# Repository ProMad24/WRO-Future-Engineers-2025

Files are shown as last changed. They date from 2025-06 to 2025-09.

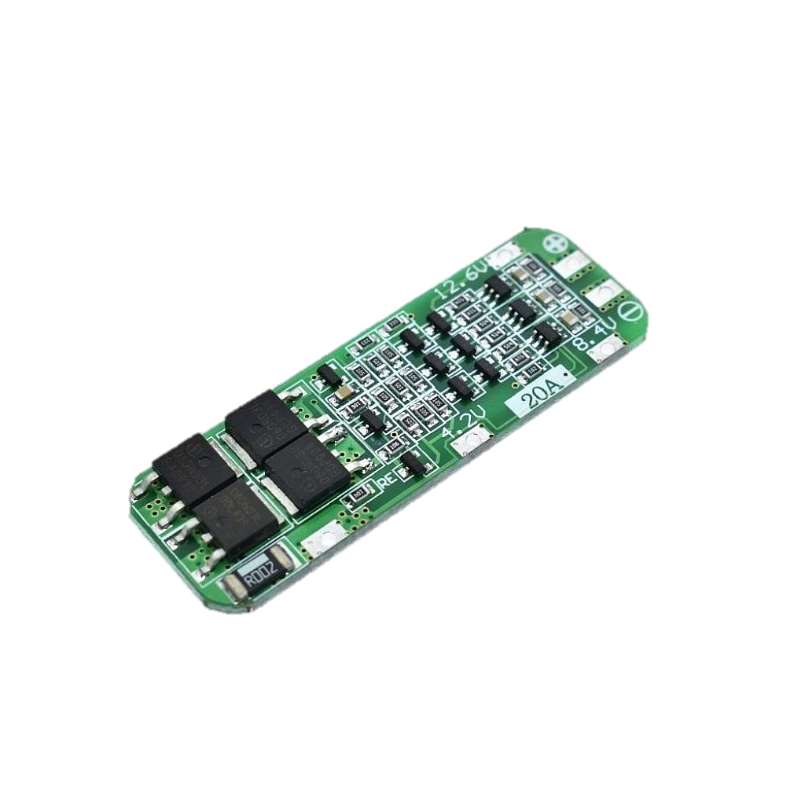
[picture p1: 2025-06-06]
Schemes and Electromechanical Components/20A Protection Circuit For The Batteries.png

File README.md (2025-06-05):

# WRO-Future-Engineers-2025
The Official WRO Future Engineers 2025 Repository of The Syrian Team ProMad

# Introdution :
In pursuit of comfort, humans have always sought easier ways of travel, one example being the self-driving car. An “autonomous” car is a vehicle capable of sensing its environment and operating without human involvement. Driven by curiosity, humanity has reached the necessary technological advancements to achieve a truly autonomous car. Thus, in our project we strive to design, then build a car that is able to move independently while making optimal decisions. Moreover, we extend this work to incorporate obstacle avoidance. In order to achieve our objectives, we developed an integrated system using a Raspberry Pi Model B, which receives and processes information to make decisions before transmitting signals to execute specific commands.

Our approach to the competition was structured into two parts, each addressing a specific challenge. However, both solutions relied on a shared core mechanism: a color-based navigation system.

To inform readers about the vehicle's design, we outline its electromechanical components in the following list:
1)	Raspberry Pi 4 Model B: This single-board computer (SBC) acts as the central processing unit of the vehicle, handling image analysis and motor control to ensure precise navigation.
2)	PiCamera Module 3: A camera designed for the Raspberry Pi, enabling image alongside video capture before transmitting data to the board for processing.
3)	G12-N20 Geared Mini DC Motor: A compact yet powerful motor that enables forward and reverse rotation of the vehicle’s rear wheels.
4)	SG90 Servo Motor: With its precise angular rotation, this servo motor is essential for steering the vehicle’s front wheels, ensuring accurate directional control.
5)	Addressable RGB LED: This LED acts as a real-time debugger for the vehicle, changing colors based on its signals and commands to provide immediate visual feedback.

For the codes with their explanation, detailed information about the electromechanical components alongside many more, feel free to explore the various folders in the repository of the team 😊.

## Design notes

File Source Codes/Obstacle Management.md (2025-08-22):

# Obstacle Challenge:
The solution implemented for this challenge integrates a color-based navigation system to complete the laps around the mat and execute the parking process. The robot utilizes its Pi Camera to detect red and green pillars, which serve as steering indicators. Upon identifying a red pillar, the system transmits signals to the Raspberry Pi, prompting a rightward steering adjustment. Conversely, detecting a green pillar triggers a leftward turn, ensuring precise directional control. The parking lot is consistently positioned within the starting section, allowing the robot to initiate its final maneuver upon completing three laps. At this stage, the system scans for magenta pixels, identifying the parking lot’s location. Following this step, the robot navigates toward the designated area, executing a controlled parking sequence. This integrated approach enhances autonomous navigation, obstacle recognition, and precise parking alignment, optimizing the robot’s overall performance.

Let’s dive into this mechanism deeper with the following steps:

**1. Starting The Robot:**
In the obstacle challenge, the robot's mechanism is activated by first turning on the main power switch, which initiates the circuit. The program is then manually started by pressing a push button. Following this boot-up sequence, the robot's image processing begins, using the same methodology as in the open challenge. This involves capturing and analyzing visual data to guide the robot's subsequent actions.

**2. Object and Wall Detection:**
Once the image is in the HSV format, the process_hsv() function analyzes the pixels to identify key elements:
•	Walls: Pixels with a low value (brightness less than 70) are identified as walls. The code calculates the density of these pixels on both the left and right sides of the frame, providing an estimate of the robot's proximity to a wall. This is a crucial input for the steering algorithm.
•	Traffic Lights: The script identifies red and green traffic lights based on their hue and saturation values. For instance, red traffic lights are identified by a hue value less than 15 or greater than 175, while green traffic lights are identified by a hue value between 45 and 90. These pixels are used to create separate masks for each color.
•	Parking Gate: A purple parking gate is detected using a similar method, identifying pixels within a specific hue, saturation, and value range to create a mask.

**3. Contour Analysis:** 
After the masks are generated, the script uses cv2.findContours() to identify contiguous shapes of each color. The process_traffic_contours() and process_parking_contours() functions then iterate through these shapes (contours) to find the largest one, which is assumed to be the target object. The x and y coordinates of the centroid of the largest contour are stored, along with its area and type (red or green).steps.

**4. Steering and Motor Control**
This is where the robot acts on the visual data. The steering direction is calculated using a proportional control (P-controller) algorithm. The Err variable, or error, is calculated based on the horizontal position of the detected traffic light. A positive error value indicates the traffic light is to the left of the center, and a negative value indicates it is to the right. The steering direction, dir, is then calculated as Err * kp, where kp is a constant gain of 0.30. This makes the steering proportional to the error, causing the robot to turn more sharply the farther it is from the center. The servo() function then takes this dir value and converts it into a PWM (Pulse Width Modulation) signal to control the servo motor, which adjusts the robot's wheels. The script also includes a fail-safe mechanism where if the wall density is too high, the robot will turn sharply away to prevent a collision.

**5. Mission Logic and Overrides:**
The code contains a complex state machine with various conditions that override the standard steering algorithm:
•	Quadrant Counting: The robot tracks its progress by counting blue and orange lines, which define different quadrants of the course.
•	Parking Sequence: In later quadrants, the script overrides the traffic light detection and initiates a new steering routine to align with and approach the parking gate. This routine uses the wall detection logic to align the robot parallel to the walls before stopping when the purple parking gate is close enough. The STOP variable is set to True to halt the robot and end the program once the mission is complete.

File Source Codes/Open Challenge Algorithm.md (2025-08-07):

# 1. Open Challenge: 

To address the challenge, we developed a camera-based algorithm utilizing the Raspberry Pi 4 Model B alongside the Pi Camera Model 3. This system enables precise linear alignment, ensuring the robot maintains a consistent trajectory along the mat’s walls throughout the four straightforward sections. The steering mechanism is dynamically adjusted based on color recognition, allowing the robot to detect and respond to walls when encountering a corner. Additionally, the system incorporates a lap-counting function relying on the strips in corners, enabling the robot to track its completed laps before executing a stop command. This integrated approach enhances autonomous navigation, spatial awareness, and real-time decision-making, optimizing the robot’s overall performance.

To further elaborate on this mechanism, the following is a step-by-step breakdown of its functionality:

### *__1.1.__ Starting The Robot:*
- Once the robot is placed on the mat, we close the robot’s circuit using a simple switch to provide it with power. Then, it initiates the program execution with a button press, activating its driving mechanism.
------
### *__1.2.__	Image Processing:*
- The Pi Camera captures an image of the robot’s field of view, transmitting it to the Raspberry Pi for processing.

- Much like the human eye, the camera is positioned to capture a flipped image at a resolution of 640×480 pixels. Upon receiving the photograph from the PiCamera 3, the Rpi4 immediately initiates the processing sequence. This sequence involves flipping the image, adjusting its resolution, and performing color detection.

- With more details, the Rpi reduces the resolution to 320×120 pixels and removes the top 40 rows to isolate the area containing the mat. Keeping in mind that it structures the pixel data into arrays using Python, while leveraging the NumPy library for efficient manipulation. This technique not only facilitates resolution reduction but also contributes to image inversion, as the pixels are reordered in reverse to produce the correct visual phase.

- We arrive at the final stage of the image processing sequence: color detection. The Rpi is responsible for identifying a variety of colors by relying on the HSV (Hue, Saturation, Value) color model, which ensures optimal detection accuracy. Specifically, the algorithm recognizes walls as black pixels, while blue and orange pixels indicate corner strips.
  
  - Moreover, color detection is contingent upon a threshold condition being met. If the pixel count does not surpass this threshold, the robot disregards the orange and blue corner strips. However, if a strip is successfully detected, its state is set to 1, indicating active detection. Once the strip moves out of view, the state transitions to 2, initiating a cooldown phase before the next strip can be registered.
  - Additionally, the algorithm designed for linear alignment relies on detecting the proportional presence of both the left and right walls. To facilitate this, the Rpi splits the image into two halves—one representing the left wall’s black pixels, and the other capturing the right wall’s black pixels—allowing the system to evaluate wall alignment more accurately based on distribution and positioning.
---
### *__1.3.__	Analysis of Given Information and Solving the Challenge:*
- As the Rpi4 interprets the robot’s field of view, it issues optimal commands to execute the designated task. The following outlines these commands step by step:

- <ins>*__Step One:__*</ins> Upon activation—triggered by pressing the start button—the DC motor immediately begins rotating at a speed of 90 RPM. Simultaneously, the PiCamera initiates image analysis.

- <ins>*__Step Two:__*</ins> The PiCamera processes 30 frames per second. For each frame, the Rpi4 evaluates the distribution of black pixels across both halves of the image. It then performs proportional calculations to assess the robot’s alignment relative to the surrounding walls and its distance from the outer boundary. If the robot is properly aligned, the Rpi4 maintains the steering wheels in a forward position without altering the angle. However, if any misalignment is detected, it adjusts the steering angle via the Servo motor using a proportional (P) controller to restore proper orientation.

- <ins>*__Step Three:__*</ins> When the robot encounters a corner, an additional condition is applied to the previous process. Specifically, if the Rpi4 detects an insufficient number of black pixels on either half of the frame, it infers the absence of a wall and authorizes an increase in the steering angle. The direction of the Servo motor’s movement—whether it turns left or right—is determined by the color of the first strip identified: orange strips signal a clockwise turn (positive angle change), while blue strips indicate a counter-clockwise turn (negative angle change).
  - Furthermore, these colored strips serve as corner counters. Each time the robot detects a strip, it increments its corner count by one. Once the count reaches twelve, the robot terminates its operation. Plus, to prevent the simultaneous detection of both strips, a brief delay is introduced following the observation of one.

- <ins>*__Added Feature:__*</ins> An Assembly LED was installed to provide visual feedback on the robot’s readings. It reflects key states such as the detection of different colors. Further details are addressed in a separate directory.

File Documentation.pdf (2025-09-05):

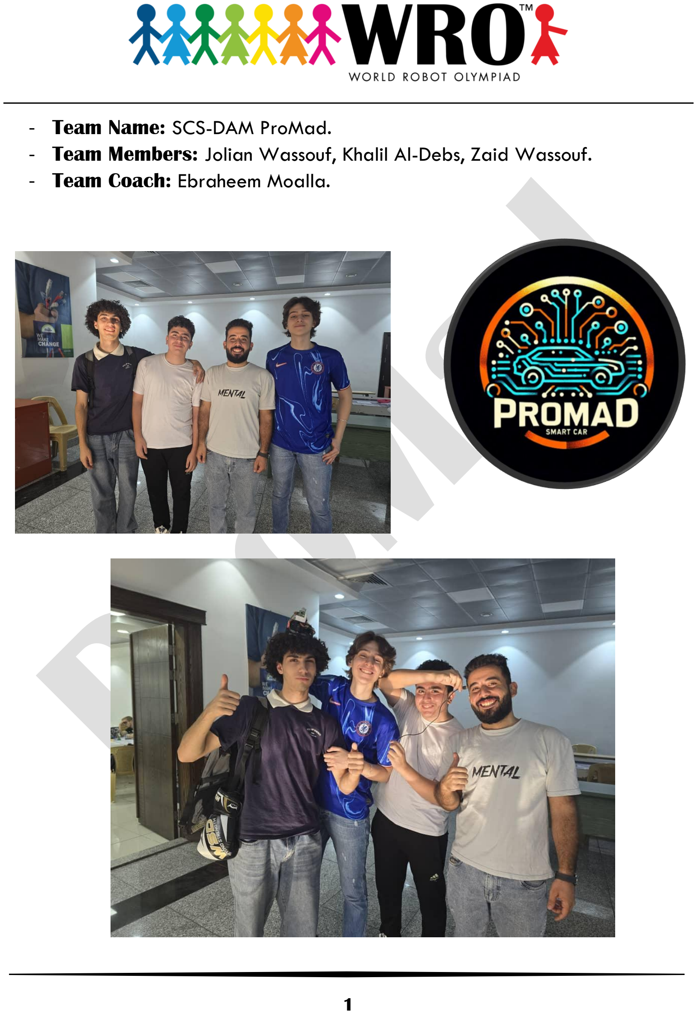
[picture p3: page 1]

1

- Team Name: SCS-DAM ProMad.
- Team Members: Jolian Wassouf, Khalil Al-Debs, Zaid Wassouf.
- Team Coach: Ebraheem Moalla.

2

## Table of Contents:

. Team Members | P.1

### 1. Introduction | P.3

### 2. Solution | P.3-12

1. Open Challenge | P.3-7
2. Obstacle Challenge | P.8-12

### 3. Mobility Management | P.13-23

1. The Steering Assembly | P.13-17
2. The Driving Assembly | P.18-21
3. The Robot’s Body / 3D Design | P.22-23
4. The Mobility Measurement | P.23

### 4. Power and Sense Management | P.24-37

1. The Robot’s Power Source | P.24-27
2. Main Components | P.28-30
3. Wiring Diagrams | P.31-32
4. Sensing | P.33-37

### 5. The Robot’s Evolution | P.38-45

1. Past | P.38-41
2. Present | P.42
3. Future | P.43-45

### 6. The Vehicle’s Photos | P.46-51

### 7. Links and Credits | P.52

3

### 1. Introduction:

In pursuit of comfort, humans have always sought easier ways of travel, one example being the self-driving car. An “autonomous” car is a vehicle capable of sensing its environment and operating without human involvement. Driven by curiosity, humanity has reached the necessary technological advancements to achieve a truly autonomous car. Thus, in our project we strive to design, then build a car that is able to move independently while making optimal decisions. Moreover, we extend this work to incorporate obstacle avoidance. In order to achieve our objectives, we developed an integrated system using a Raspberry Pi 4 Model B, which receives and processes information to make decisions before transmitting signals to execute specific commands.

### 2. Solution:

We followed a solution of two parts, one for each task.

### 1. Open Challenge:

To address the challenge, we developed a camera-based algorithm utilizing the Raspberry Pi 4 Model B alongside the Pi Camera Model 3. This system enables precise linear alignment, ensuring the robot maintains a consistent trajectory along the mat’s walls throughout the four straightforward sections. The steering mechanism is dynamically adjusted based on color recognition, allowing the robot to detect and respond to walls when encountering a corner. Additionally, the system incorporates a lap-counting function relying on the strips in corners, enabling the robot to track its completed laps before executing a stop command. This integrated approach enhances autonomous navigation, spatial awareness, and real-time decision-making, optimizing the robot’s overall performance. Lines of code in addition to performance videos are provided in the Links section.

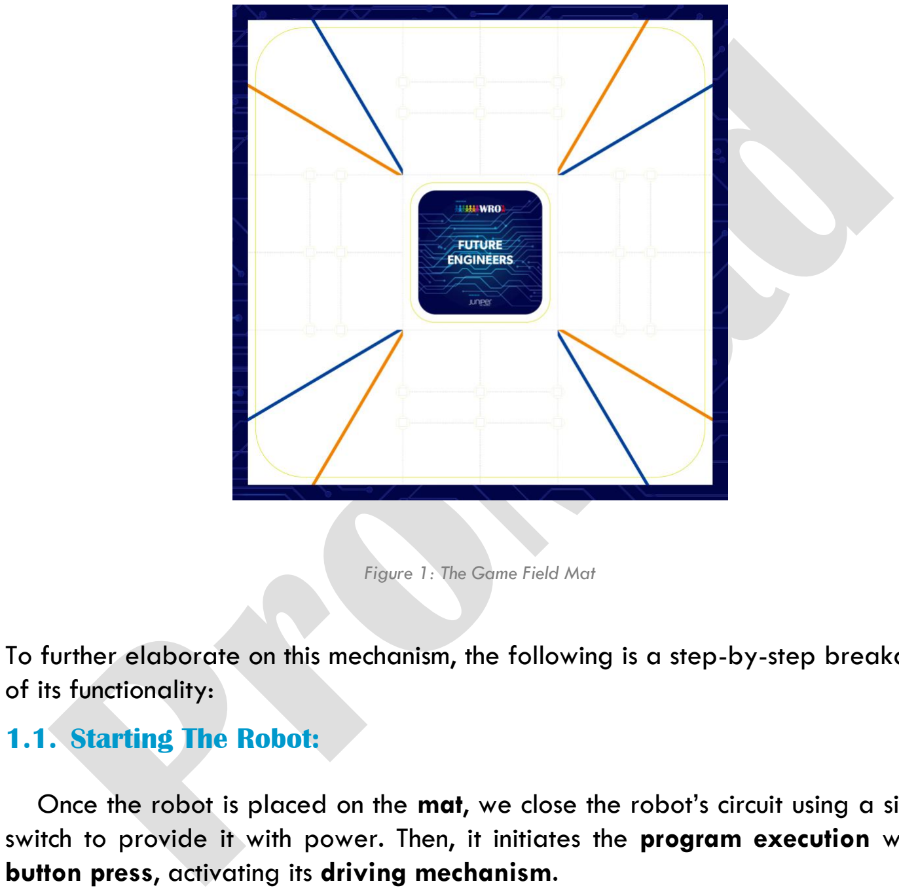
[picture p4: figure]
of its functionality:; 1.1. Starting The Robot:; Figure 1: The Game Field Mat

4

To further elaborate on this mechanism, the following is a step-by-step breakdown

Once the robot is placed on the mat, we close the robot’s circuit using a simple switch to provide it with power. Then, it initiates the program execution with a button press, activating its driving mechanism.

### 1.2. Image Processing:

The Pi Camera captures an image of the robot’s field of view, transmitting it to the Raspberry Pi 4 Model B for processing.

5

Much like the human eye, the camera is positioned to capture a flipped image at a resolution of 640×480 pixels. Upon receiving the photograph from the PiCamera 3, the Raspberry Pi 4 immediately initiates the processing sequence. This sequence involves flipping the image, adjusting its resolution, and performing color detection.

With more details, the Rpi4 reduces the resolution to 320×120 pixels and removes the top 40 rows to isolate the area containing the mat. Keeping in mind that it structures the pixel data into arrays using Python, while leveraging the NumPy library for efficient manipulation. This technique not only facilitates resolution reduction but also contributes to image inversion, as the pixels are reordered in reverse to produce the correct visual phase.

Figure 3: Raw Image | Figure 2: Processed Image

6

We arrive at the final stage of the image processing sequence: color detection. The Raspberry Pi 4 is responsible for identifying a variety of colors by relying on the HSV (Hue, Saturation, Value) color model, which ensures optimal detection accuracy. Specifically, the algorithm recognizes walls as black pixels, while blue and orange pixels indicate corner strips.

Moreover, color detection is contingent upon a threshold condition being met. If the pixel count does not surpass this threshold, the robot disregards the orange and blue corner strips. However, if a strip is successfully detected, its state is set to 1, indicating active detection. Once the strip moves out of view, the state transitions to 2, initiating a cooldown phase before the next strip can be registered.

Additionally, the algorithm designed for linear alignment relies on detecting the proportional presence of either the left or right walls. To facilitate this, the Rpi4 splits the image into two halves—one representing the left wall’s black pixels, and the other capturing the right wall’s black pixels—allowing the system to evaluate wall alignment more accurately based on distribution and positioning.

Figure 5: Walls Detection –
walls are the white figures | Figure 4: The Robot's View of The Lines

Figure 6: The Identification of Strip Colors

*Blue | *Orange

7

### 1.3. Analysis of Given Information and Solving the Challenge:

As the Rpi4 interprets the robot’s field of view, it issues optimal commands to execute the designated task. The following outlines these commands step by step:

Step One: Upon activation—triggered by pressing the start button—the DC motor immediately begins rotating at a speed of 200 RPM. Simultaneously, the PiCamera initiates image analysis.

Step Two: The PiCamera processes 30 frames per second. For each frame, the Rpi4 evaluates the distribution of black pixels across both halves of the image. It then performs proportional calculations to assess the robot’s alignment relative to the surrounding walls and its distance from the outer boundary. If the robot is properly aligned, the Rpi4 maintains the steering wheels in a forward position without altering the angle. However, if any misalignment is detected, it adjusts the steering angle via the Servo motor using a proportional (P) controller to restore proper orientation.

Step Three: When the robot encounters a corner, the wall that the robot relies on for the proportions—whether it is the left or right wall—is determined by the color of the first strip identified: orange strips signal a clockwise turn (left wall proportion), while blue strips indicate a counter-clockwise turn (right wall proportion).

Furthermore, these colored strips serve as corner counters. Each time the robot detects a strip, it increments its quadrant count by one. Once the count reaches twelve, the robot terminates its operation. Plus, to prevent the simultaneous detection of both strips, a brief delay is introduced following the observation of one.

Added Feature: An Assembly LED was installed to provide visual feedback on the robot’s readings. It reflects key states such as the detection of different colors. Further details are addressed in a separate directory.

8

Figure 7: Obstacle Challenge Map

### 2. Obstacle Challenge:

The solution implemented for this challenge integrates a color-based navigation system to complete the laps around the mat and execute the parking process. The robot utilizes its Pi Camera to detect red and green pillars, which serve as steering indicators. Upon identifying a red pillar, the system transmits signals to the Raspberry Pi, prompting a rightward steering adjustment. Conversely, detecting a green pillar triggers a leftward turn, ensuring precise directional control. The parking lot is consistently positioned within the starting section, allowing the robot to initiate its final maneuver upon completing three laps. At this stage, the system scans for magenta pixels, identifying the parking lot’s location. Following this step, the robot navigates toward the designated area, executing a controlled parking sequence. This integrated approach enhances autonomous navigation, obstacle recognition, and precise parking alignment, optimizing the robot’s overall performance. Lines of code besides performance videos are provided as a QR code in the Links section.

9

Let’s dive into this mechanism deeper with the following steps:

### 2.1. Starting The Robot:

In the obstacle challenge, the robot's mechanism is activated by first turning on the main power switch, which initiates the circuit. The program is then manually started by pressing a push button. Following this boot-up sequence, the robot's image processing begins, using the same methodology as in the open challenge. This involves capturing and analyzing visual data to guide the robot's subsequent actions.

### 2.2. Object and Wall Detection:

Once the image is in the HSV format, the process_hsv() function analyzes the pixels to identify key elements:

- Walls: Pixels with a low value (brightness less than 70) are identified as walls. The code calculates the density of these pixels on both the left and right sides of the frame, providing an estimate of the robot's proximity to a wall. This is a crucial input for the steering algorithm.
- Traffic Lights: The script identifies red and green traffic lights based on their hue and saturation values. For instance, red traffic lights are identified by a hue value less than 15 or greater than 175, while green traffic lights are identified by a hue value between 45 and 90. These pixels are used to create separate masks for each color.
- Parking Gate: A purple parking gate is detected using a similar method, identifying pixels within a specific hue, saturation, and value range to create a mask.

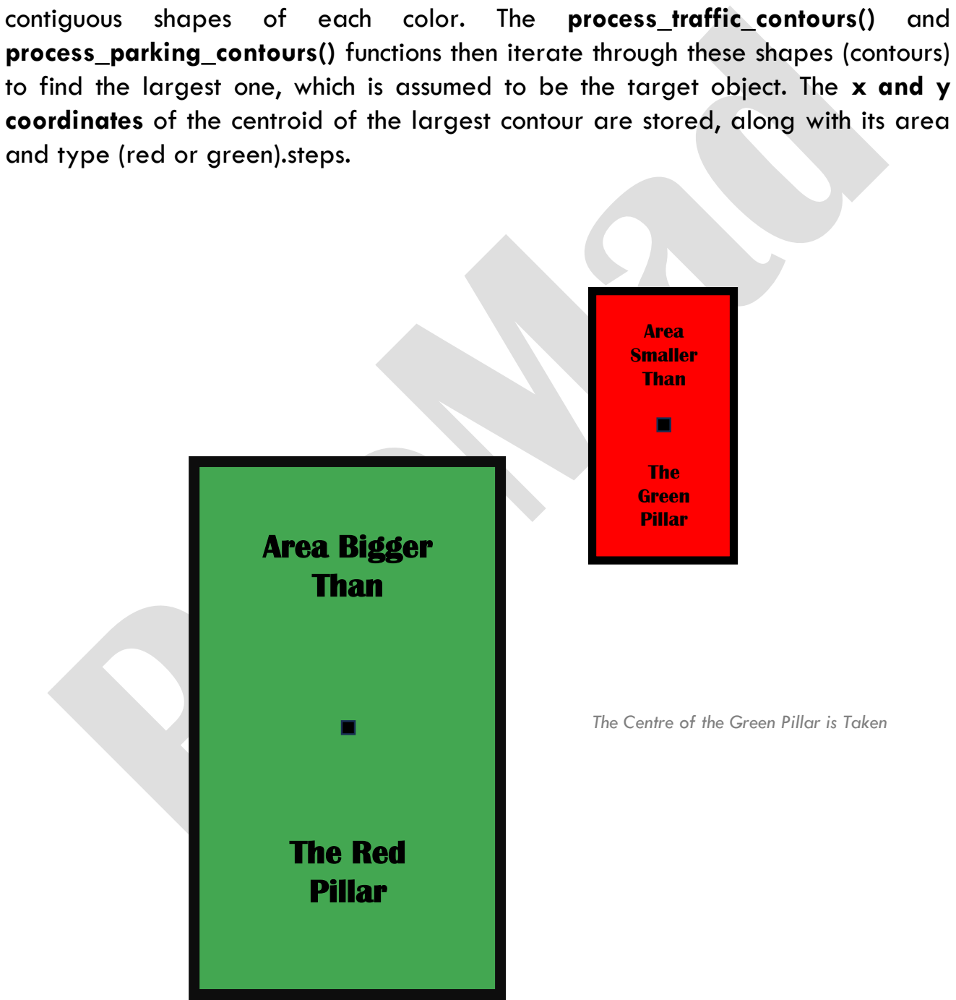
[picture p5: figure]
contiguous; shapes; each; color.; The; process_traffic_contours(); and; and type (red or green).steps.; Area Bigger Than; The Red Pillar; The Centre of the Green Pillar is Taken; Area Smaller Than; The Green Pillar

10

### 2.3. Contour Analysis:

After the masks are generated, the script uses cv2.findContours() to identify

process_parking_contours() functions then iterate through these shapes (contours) to find the largest one, which is assumed to be the target object. The x and y coordinates of the centroid of the largest contour are stored, along with its area

11

### 2.4. Steering and Motor Control

This is where the robot acts on the visual data. The steering direction is calculated using a proportional control (P-controller) algorithm. The Err variable, or error, is calculated based on the horizontal position of the detected traffic light. A positive error value indicates the traffic light is to the left of the center, and a negative value indicates it is to the right. The steering direction, dir, is then calculated as Err * kp, where kp is a constant gain of 0.30. This makes the steering proportional to the error, causing the robot to turn more sharply the farther it is from the center. The servo() function then takes this dir value and converts it into a PWM (Pulse Width Modulation) signal to control the servo motor, which adjusts the robot's wheels. The script also includes a fail-safe mechanism where if the wall density is too high, the robot will turn sharply away to prevent a collision.

Figure 8: Obstacle Management

12

### 2.5. Mission Logic and Overrides:

The code contains a complex state machine with various conditions that override the standard steering algorithm:

- Quadrant Counting: The robot tracks its progress by counting blue and orange lines, which define different quadrants of the course.
- Parking Sequence: In later quadrants, the script overrides the traffic light detection and initiates a new steering routine to align with and approach the parking gate. This routine uses the wall detection logic to align the robot parallel to the walls before stopping when the purple parking gate is close enough. The STOP variable is set to True to halt the robot and end the program once the mission is complete.

13

### 3. Mobility Management:

To clarify how we managed the robot’s mobility, we’re willing to discuss several aspects:

### 1. The Steering Assembly:

To steer the robot properly, we used:

- MG90s Servo Motor:

The MG90s servo motor was specifically selected for this application due to its compact dimensions and its capacity for exceptionally precise angle management. Operating within a voltage range of 4.8V to 6V, it facilitates a full 180° rotation span, which is ideal for angular control tasks. Internally, its accurate motion is regulated by a sophisticated control circuit, which, coupled with a potentiometer for positional feedback, directs a DC motor and gear train. This regulation is achieved via Pulse Width Modulation (PWM) signals, where specific pulse durations within a 20ms cycle correspond to exact angles—a 1.5ms pulse for the center position, with 1ms and 2ms pulses for the opposing extremes.

Furthermore, its performance capabilities are substantiated by a stall torque of approximately 1.8 kg-cm at 4.8V and a rapid response time of 0.10–0.12 seconds per 60° of rotation. The unit's lightweight design, high responsiveness, and seamless integration through a simple three-wire interface (power, ground, and signal) affirm its suitability for tasks demanding precise and dynamic motion control.

Figure 9: MG90s Mini Servo Motor

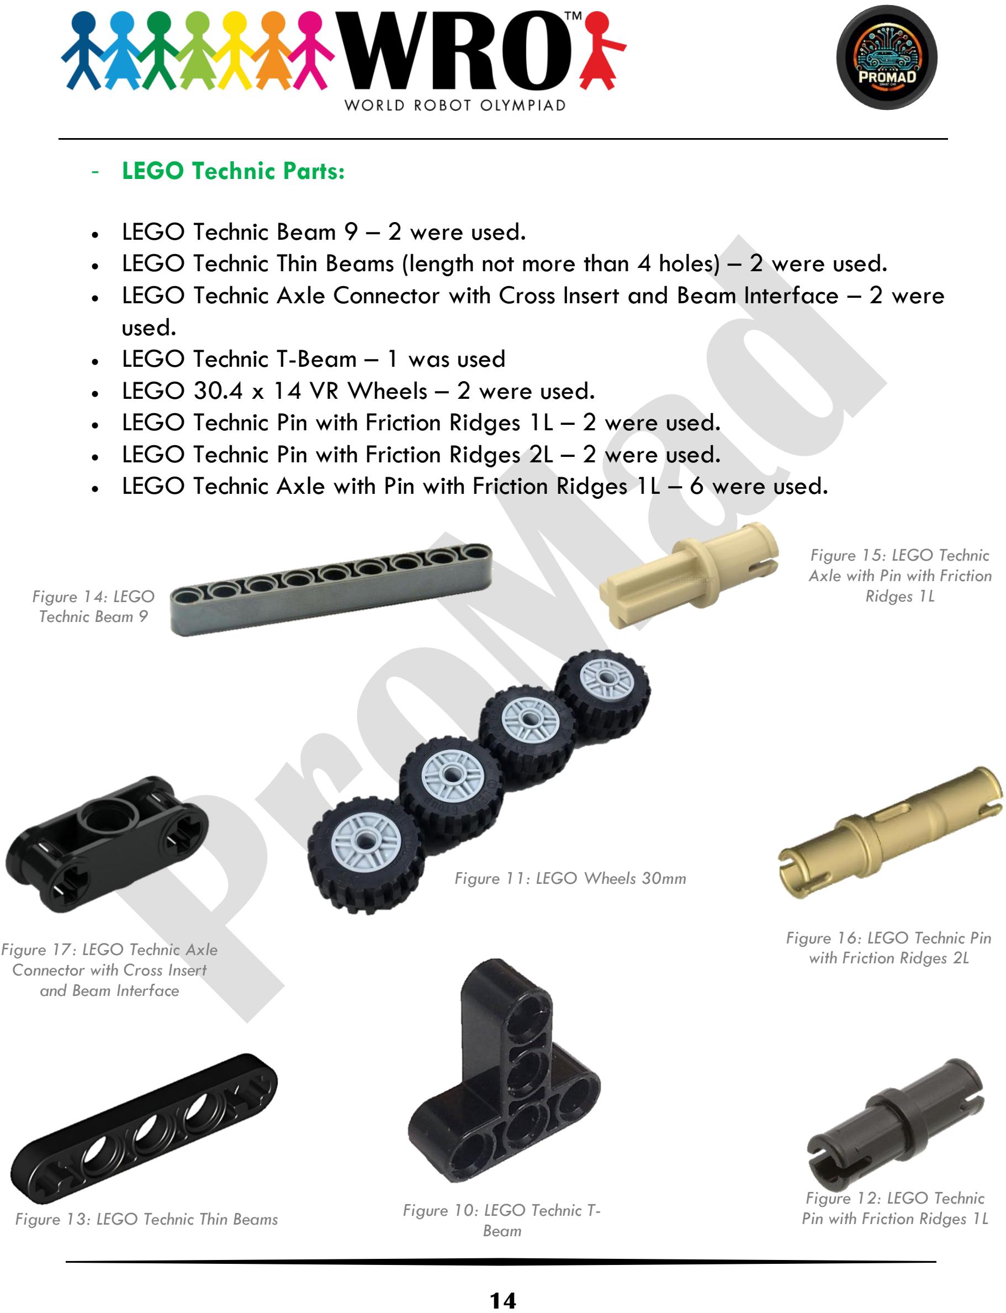
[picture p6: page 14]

14

- LEGO Technic Parts:
- LEGO Technic Beam 9 – 2 were used.
- LEGO Technic Thin Beams (length not more than 4 holes) – 2 were used.
- LEGO Technic Axle Connector with Cross Insert and Beam Interface – 2 were used.
- LEGO Technic T-Beam – 1 was used
- LEGO 30.4 x 14 VR Wheels – 2 were used.
- LEGO Technic Pin with Friction Ridges 1L – 2 were used.
- LEGO Technic Pin with Friction Ridges 2L – 2 were used.
- LEGO Technic Axle with Pin with Friction Ridges 1L – 6 were used.

Figure 15: LEGO Technic
Axle with Pin with Friction
Figure 14: LEGO | Ridges 1L
Technic Beam 9

Figure 17: LEGO Technic Axle Connector with Cross Insert and Beam Interface

Figure 16: LEGO Technic Pin with Friction Ridges 2L

Figure 13: LEGO Technic Thin Beams

Figure 12: LEGO Technic
Pin with Friction Ridges 1L

Figure 11: LEGO Wheels 30mm

Figure 10: LEGO Technic T-Beam

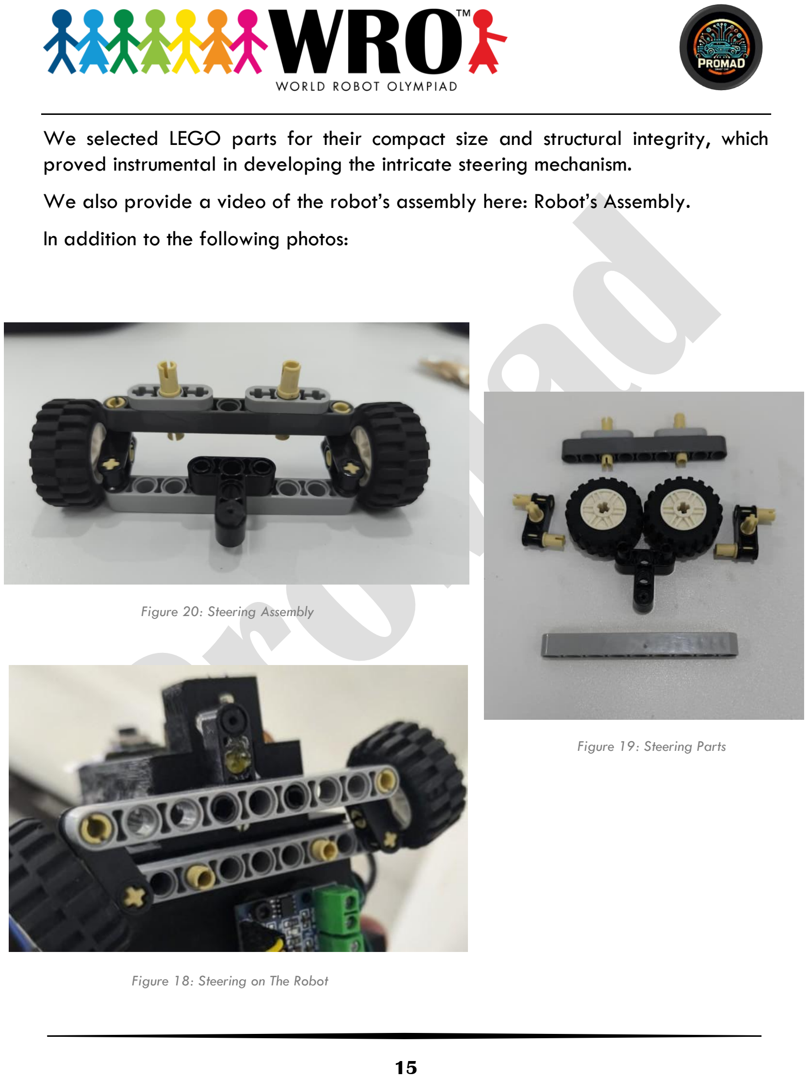
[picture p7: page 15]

15

We selected LEGO parts for their compact size and structural integrity, which proved instrumental in developing the intricate steering mechanism.

We also provide a video of the robot’s assembly here: Robot’s Assembly.

In addition to the following photos:

Figure 20: Steering Assembly

Figure 19: Steering Parts

Figure 18: Steering on The Robot

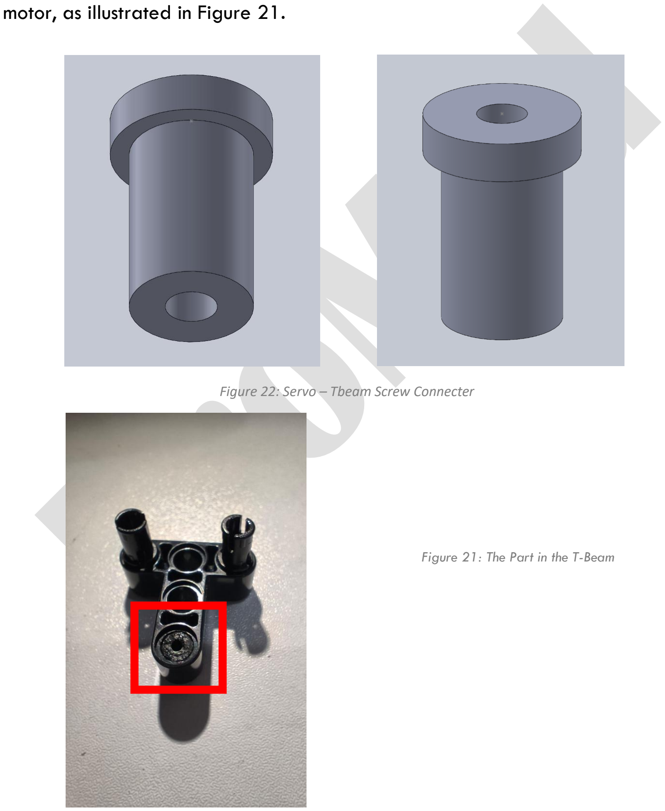
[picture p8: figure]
motor, as illustrated in Figure 21.; Figure 21: The Part in the T-Beam

16

- 3D Part:

This component served as a screw holder, connecting the T-Beam and the servo

Figure 22: Servo – Tbeam Screw Connecter

17

The Steering Algorithm:

The steering logic is implemented in the cycle() function, which is continuously called in the main loop to provide a near real-time response. In the open challenge, the algorithm steers the robot by detecting walls on either side of the path. It calculates an error term based on the number of "wall" pixels detected and then determines the steering direction, dir, by multiplying this error by the proportional gain constant. The calculated dir value is then passed to the servo() function. Similarly, the obstacle challenge also uses wall detection but incorporates more complex logic based on the detection of traffic lights and parking gates. The error term, Err, is derived from the position of the detected traffic light, and the steering is adjusted accordingly. The cycle() function in both codes is executed repeatedly, ensuring the steering is constantly adjusted with each new frame captured by the camera.

18

Figure 23: GA12-N20 Geared Mini DC Motor

### 2. The Driving Assembly:

The driving assembly has a simple idea, let’s navigate it with starting with the components first:

- GA12-N20 Geared Mini DC Motor:

The N20 DC 12V 150RPM gear motor was an ideal choice for this project. We selected this motor specifically for its power efficiency, compact size, and potent drive power, all of which were crucial to our robot's design. The motor's small dimensions were paramount, as they allowed for a streamlined and space-efficient build. Furthermore, the motor's high-torque output, which delivers a rated torque of approximately 2.5 kg-cm and a stall torque reaching nearly 8 kg-cm under heavy loads, provides the robust and responsive movement required for our system. A durable metal gearbox further enhances longevity and reduces wear over time. This motor's compact design, impressive torque efficiency, and robust construction made it a versatile and essential component for our technical application, ensuring reliable performance even in demanding conditions.

19

- L9110 Motor Driver:

The L9110 motor driver is a highly efficient PWM-based control IC designed for high-voltage applications, particularly in automotive and industrial environments. Engineered to regulate LED brightness and motor speed, it operates within a wide voltage range, ensuring adaptability across various systems. The L9110 supports high-current outputs, making it suitable for power-intensive applications. Its integrated protection mechanisms, including overcurrent and thermal shutdown, enhance reliability and longevity. The PWM control ensures precise modulation, optimizing energy efficiency while minimizing heat dissipation. With its compact design and robust electrical specifications, the L9110 stands as a versatile solution for engineers seeking stable and efficient motor control.

In our project, it used with the DC Motor.

Figure 24: L9110 Motor Driver

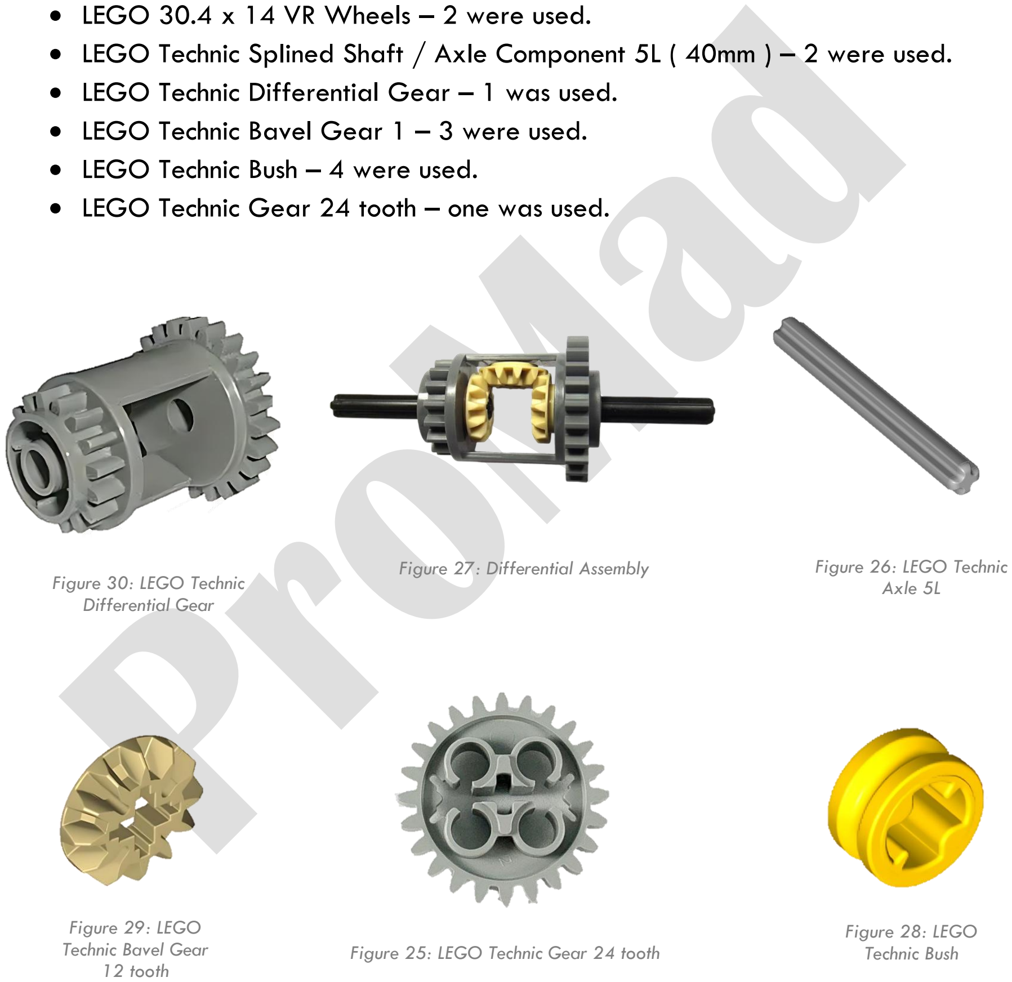
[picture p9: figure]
• LEGO Technic Bush – 4 were used.; Figure 26: LEGO Technic Axle 5L Figure 30: LEGO Technic Differential Gear; Figure 29: LEGO Technic Bavel Gear 12 tooth; Figure 28: LEGO; Figure 27: Differential Assembly

20

- LEGO Parts:
- LEGO 30.4 x 14 VR Wheels – 2 were used.
- LEGO Technic Splined Shaft / Axle Component 5L ( 40mm ) – 2 were used.
- LEGO Technic Differential Gear – 1 was used.
- LEGO Technic Bavel Gear 1 – 3 were used.
- LEGO Technic Gear 24 tooth – one was used.
Figure 25: LEGO Technic Gear 24 tooth | Technic Bush

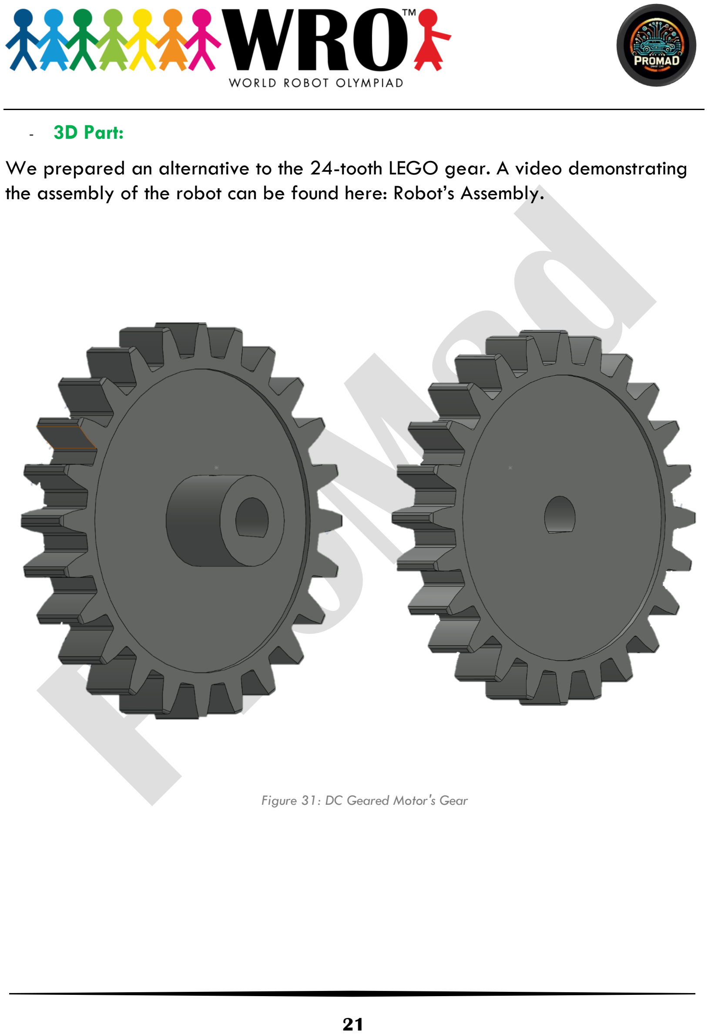
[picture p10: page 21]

21

- 3D Part:

We prepared an alternative to the 24-tooth LEGO gear. A video demonstrating the assembly of the robot can be found here: Robot’s Assembly.

Figure 31: DC Geared Motor's Gear

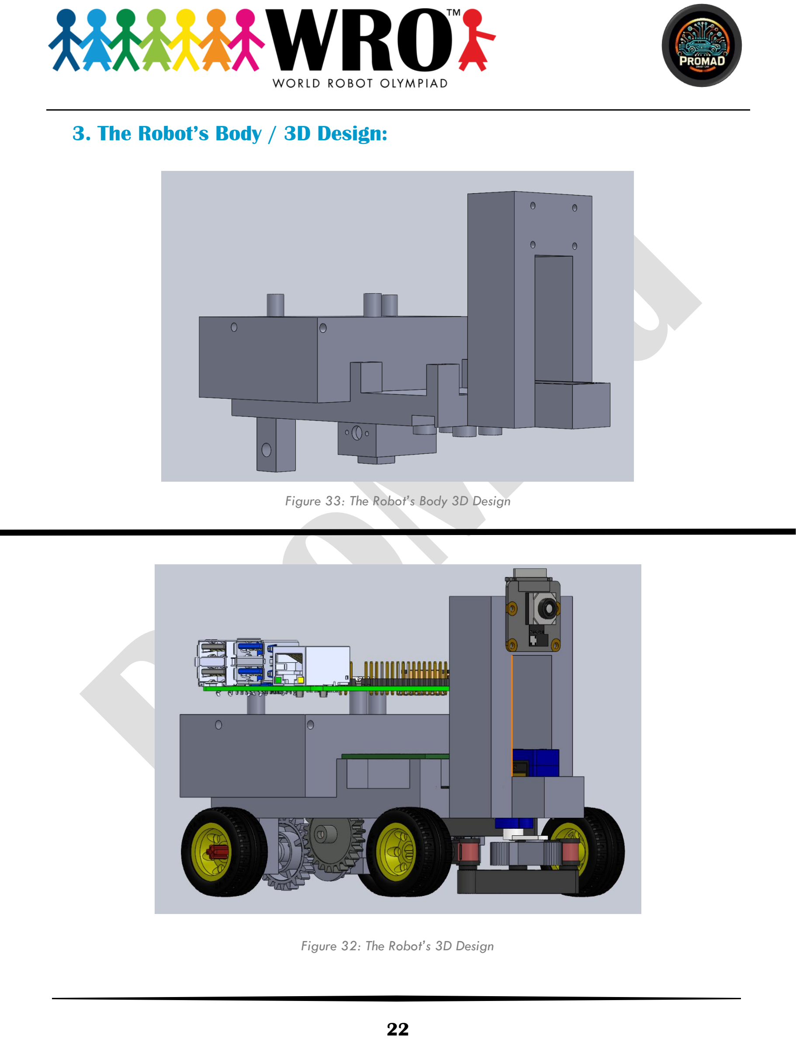
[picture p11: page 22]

22

### 3. The Robot’s Body / 3D Design:

Figure 33: The Robot’s Body 3D Design

Figure 32: The Robot’s 3D Design

23

In selecting the robot's body, our objective was to design a novel and practical model that would effectively address the requirements of the provided challenges. We, therefore, engineered a compact model that could accommodate all necessary components while maintaining a small footprint. For a detailed guide on the robot's assembly, a link to the instructional video can be found in the "Links" section.

### 4. The Mobility Measurement:

In order to accurately calculate the robot's velocity and power output, it is essential to first identify the following parameters:

- The Perimeter of the wheels (Pw):

{we need the radius of the wheels: rw = 30.4mm/2 => rw ≈ 0.015m}

Pw = 2πrw = 2 ⋅ 3.14 ⋅ 0.015 ≈ 0.095m

- The Speed of the motor (wdc): ωⅆc = 150Rpm
- The Voltage and Current supplied to the motor: I = 0.8A || V = 12V

The Velocity of the Robot:
v = Pw ⋅ ωⅆc = 0.095 ⋅ 150 ≈ 14.31 m ⋅ min⁻¹

v ≈ 0.238 m ⋅ s⁻¹

The Power of the Robot

P = V ⋅ I = 12 ⋅ 0.8 = 9.6 Watt

24

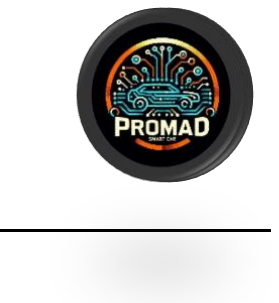
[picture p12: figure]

### 4. Power and Sense Management:

We divide this category into four sections:

### 1. The Robot’s Power Source:

1.1. 3S LiPo Battery Pack with 20A Protection Circuit:

The 3S Lithium Polymer (LiPo) battery pack consists of three cells in series, delivering a nominal voltage of 11.1V and a maximum of 12.6V when fully charged. It features an integrated 20A Battery Management System (BMS) that protects against overcharging, deep discharging, and short circuits, ensuring safe and reliable power delivery.

Thanks to its lightweight pouch construction, the LiPo pack offers flexibility and compactness, which are especially advantageous in robotic applications. Its ability to provide high discharge rates with minimal voltage drop makes it ideal for systems demanding bursts of power. Due to its excellent energy density, thermal stability, and protective features, this pack serves as the primary power source for our robot, enabling efficient, high-performance operation.

Figure 6: 20A Battery Management System (BMS)

Figure 34: LiPo Battery 2500mAh

25

### 1.2. Mini 360 DC-DC Buck Converter // 1.3. DC-DC Buck Converter

Module with USB Type-A Output:

The Mini 360 DC-DC Buck Converter is a compact and efficient voltage regulation module designed to step down higher DC voltages to a lower, adjustable output. Built around the MP2307 chip, it operates within an input range of 4.75V to 23V and delivers an output voltage adjustable between 1V and 17V. Despite its small size—just 17mm by 11mm—it supports a peak current of 3A and a continuous current of 1.8A, making it suitable for applications in robotics, DIY electronics, and embedded systems. In our robot, this module is specifically used to convert the 12V supplied by the batteries into a stable 5V output, which is essential for powering the servo motor and the assembly LED. Its high conversion efficiency, thermal shutdown protection, and onboard potentiometer for voltage tuning make it a reliable choice for compact power management.

In contrast, the DC-DC Buck Converter Module with USB Type-A Output is tailored for powering USB devices directly from a higher voltage source. Typically supporting an input range of 6V to 24V, it steps down the voltage to a fixed 5V output via a standard USB Type-A port, delivering up to 3A of current. This module is ideal for charging smartphones, powering microcontrollers, or supplying regulated 5V to embedded systems. In our robot, it serves the critical function of converting the same 12V battery input into a suitable 5V output for the Raspberry Pi 4 Model B, ensuring stable operation and protecting the board from voltage fluctuations. Its plug-and-play design, built-in protection features, and compatibility with common USB-powered devices make it especially useful in automotive, solar, and portable electronics applications.

Figure 36: Mini 360
DC-DC Buck
Converter

Figure 35: DC-DC Buck
Converter Module with
USB Type-A Output

26

### 1.4. Perfboard // 1.5. Switch:

The Perfboard in our robot serves as the central hub for electrical connectivity, linking all major components into a cohesive and efficient system. It features two input pins designated for the positive and negative poles of the LiPo battery series, which supply the primary 12V power source. Additionally, the board includes a dedicated row of GND pins that are directly connected to the Raspberry Pi 4 Model B, ensuring a stable ground reference across all subsystems. To distribute power effectively, the perfboard provides six output pins for 12V and six output pins for 5V, the latter being regulated through the Mini 360 DC-DC Buck Converter.

Furthermore, the perfboard integrates a USB Type-A converter module, which plays a crucial role in delivering a regulated 5V supply to the Raspberry Pi

### 4 Model B. This setup not only simplifies the wiring architecture but also enhances

the reliability and safety of the robot’s power distribution. By consolidating power inputs, outputs, and grounding into a single board, the perfboard ensures that all components—from servo motors to LEDs—operate smoothly and in coordination, making it an essential element of our robotic system.

And surely, we use a switch to close or open the circuit.

Figure 37: Perfboard | Figure 38: Switch

27

1.6. 470uF 25V Capacitor:

To ensure stable power delivery in our robotic system, especially during motor startup and sudden load transitions, we incorporated a 470 µF / 25 V electrolytic capacitor across the motor driver’s supply rail. This capacitor serves as a local energy reservoir, discharging rapidly when the motor demands a surge of current. By doing so, it prevents voltage dips that could disrupt the operation of critical components such as the Raspberry Pi 4, the PiCamera v3, and the push button interface. We selected this specific capacitance and voltage rating to strike a balance between energy storage capacity and spatial efficiency within the robot’s enclosure. Its presence significantly reduces transient drops and electrical noise, helping us maintain consistent system behavior under dynamic operating conditions

Figure 39: 470uF 25V Capacitor

28

### 2. Main Components:

### 2.1. Pi Camera Module 3:

The Raspberry Pi Camera Module 3 is a state-of-the-art imaging solution designed for seamless integration with Raspberry Pi devices. Equipped with a 12MP Sony IMX708 sensor, it provides autofocus, HDR capability, and enhanced low-light performance, ensuring exceptional image clarity across various applications. Available in standard and wide-angle configurations, as well as NoIR variants for infrared imaging, it offers versatile functionality. With full HD video recording at 30fps, it integrates effortlessly into Raspberry Pi’s open-source camera ecosystem, making it an indispensable tool for photography, live streaming, and AI-driven image processing, thereby pushing creative and technical boundaries.

In our project, the Pi Camera plays a
crucial role in visual data acquisition and object
recognition. It detects black pixels, which represent the walls of the mat, ensuring accurate environmental mapping. Additionally, it identifies orange and blue pixels, marking the four corner lines for precise spatial localization. The camera further recognizes red and green pixels, signifying obstacle pillars, enabling effective navigation and collision avoidance. Moreover, it detects magenta pixels, which represent the walls of the parking lot, allowing for structured positioning within the designated area. Once the visual data is captured, the Pi Camera transmits these signals to the Raspberry Pi, where computational algorithms process the information for real-time analysis and decision-making. This integrated system enhances object detection, spatial awareness, and autonomous control, ensuring optimal performance in dynamic environments.

Figure 7: Raspberry Pi Camera Module 3

29

### 2.2. Raspberry Pi 4 Model B:

The Raspberry Pi 4 Model B is a high-performance single-board computer (SBC) featuring a Broadcom BCM2711 quad-core Cortex-A72 processor clocked at 1.8GHz, our version in this project uses 2GB of LPDDR4-3200 SDRAM. It includes dual micro-HDMI ports for dual 4K display support, Gigabit Ethernet, Bluetooth 5.0, and dual-band Wi-Fi (2.4GHz & 5.0GHz). The board offers two USB 3.0 and two USB 2.0 ports, a 40-pin GPIO header, and MIPI DSI/CSI interfaces for peripherals. The 40-pin GPIO header supports digital I/O, PWM, I2C, SPI, and UART, and it is commonly programmed using Python libraries like RPi.GPIO besides Scratch. The board is powered via USB-C (5V, 3A) and supports Power over Ethernet with an optional PoE HAT.

In our project, this compact yet powerful device, powered by the USB Type-A converter module, serves as the
central processing unit, executing
and managing all computational
commands | essential | for | system
operation. It precisely coordinates the wheel motors, enabling smooth and controlled mobility. Additionally, it
interfaces | with | the | camera,
facilitating image processing and environmental awareness. Beyond these core functions, the device seamlessly integrates with various
components, | ensuring | efficient
communication and execution of all robotic commands. Its high-speed processing capabilities and multi-functional adaptability make it a crucial element in optimizing the
robot's | performance,
responsiveness, and autonomous functionality.

Figure 8: Raspberry Pi 4 Model B

30

### 2.3. WS2812B Assembly LED: **feedback component** // 2.4. Push

Button:

The WS2812B assembly LED is a highly integrated, individually addressable RGB lighting solution that combines a 5050-sized SMD LED with an embedded control IC in a single package. This integration allows each LED to be controlled independently via a single-wire digital interface, significantly simplifying circuit design and reducing the number of required microcontroller pins. Operating within a 3.3V to 5V range, each LED can produce over 16 million colors by modulating the intensity of its red, green, and blue channels through 8-bit PWM control. The data signal propagates from one LED to the next, enabling seamless daisy-chaining of multiple units without complex wiring. This makes the WS2812B ideal for dynamic lighting applications, including status indicators, visual feedback systems, and aesthetic enhancements in embedded and robotic platforms.

In our robot, the WS2812B assembly LED functions as a dynamic visual feedback system, reflecting real-time sensor readings. It is powered via a regulated 5V line from the Mini 360 Buck Converter, with ground referenced to the Raspberry Pi 4 Model B, and controlled through a GPIO pin using libraries like Adafruit NeoPixel. The LED color corresponds to environmental cues detected by the camera: when blue pixels are identified, the robot converts HSV data to RGB and displays blue; similarly, orange, red, green, and magenta are shown when their respective strips or pillars are recognized. This mapping allows quick visual confirmation of object detection and classification. Additionally, a default color is used to indicate the robot’s idle or standby state, ensuring continuous status awareness during operation.

The Push Button is used to start the program.

Figure 40: Push Button | Figure 41: WS2812B Assembly LED

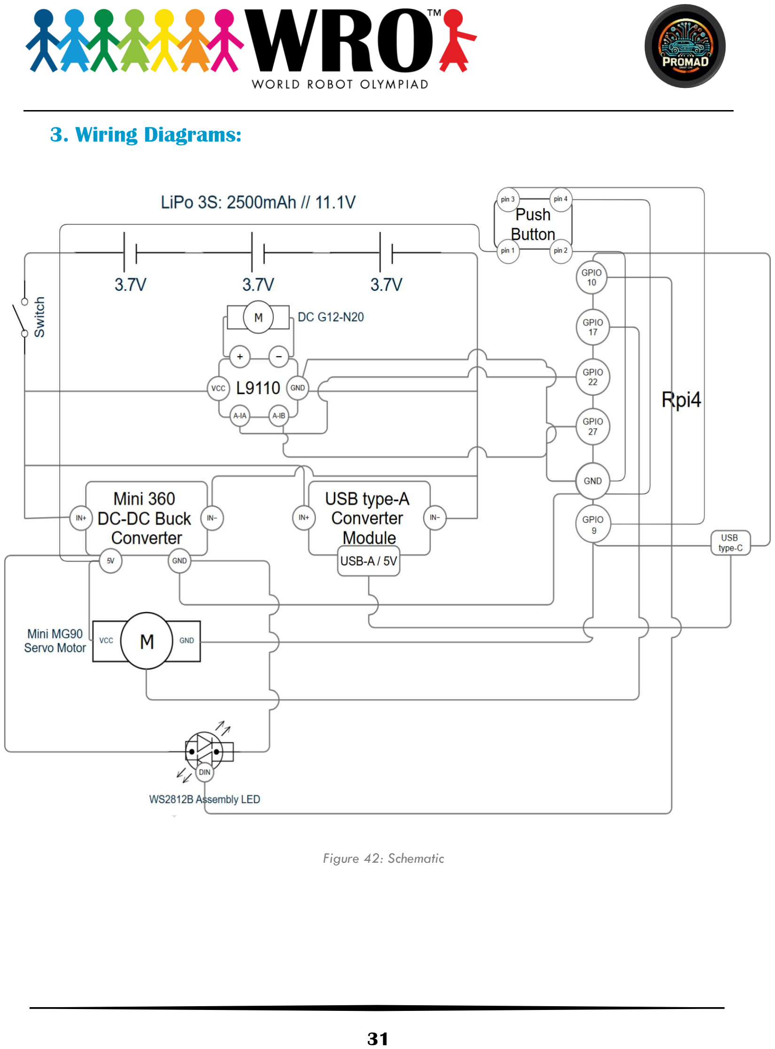
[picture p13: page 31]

31

### 3. Wiring Diagrams:

Figure 42: Schematic

GPIO
9

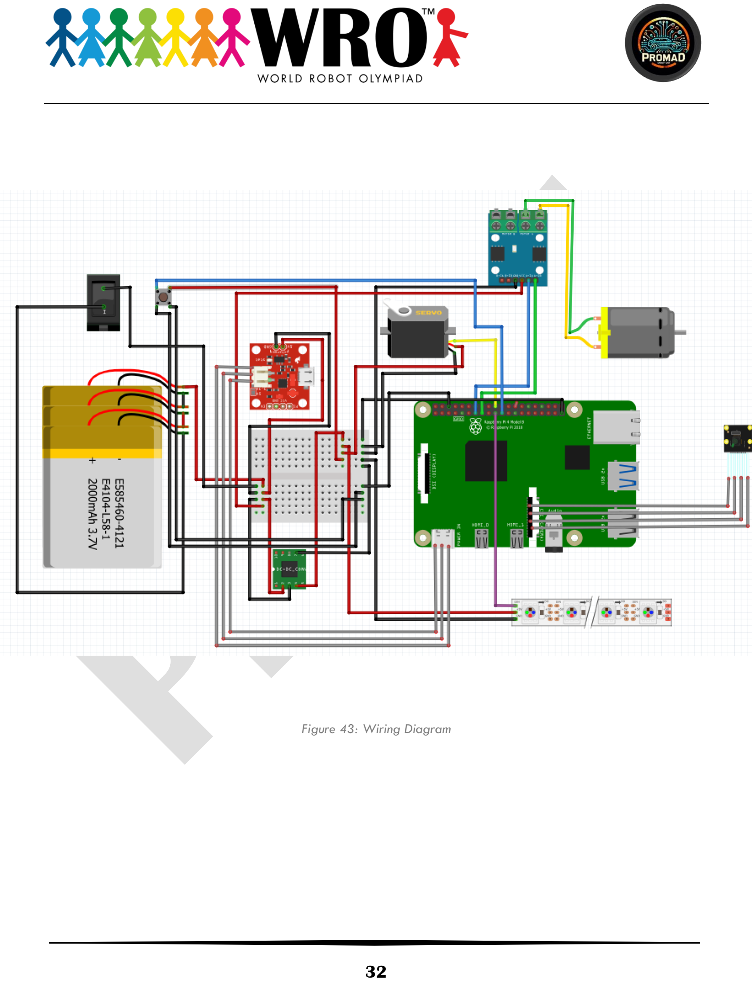
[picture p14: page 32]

32

Figure 43: Wiring Diagram

- CL 405080
3.7V 2500mAh 23A

33

### 4. Sensing:

### 4.1 Vision-Based Navigation Algorithm:

I. Image Acquisition and Pre-processing:
1. Image Capture: The system initializes the PiCamera and configures it to capture a 640x480 resolution image in an RGB888 format. This raw, high-resolution frame serves as the primary source of environmental data for each operational cycle.
2. Downsampling and Flipping: To optimize computational efficiency, the high-resolution 640x480 image is not processed directly. Instead, it undergoes a custom downsampling and vertical flipping transformation. The algorithm iterates through every second row and every second column of the bottom half of the raw frame (from row 240 to 479). This effectively reduces the image to a more manageable 320x120 resolution. The vertical flip is a result of the specific loop structure that populates the new image array from the end to the beginning, which orients the frame as if viewed from directly above and in front of the robot.
3. Color Space Conversion: The downsampled 320x120 RGB frame is immediately converted to the HSV (Hue, Saturation, Value) color space. This is a critical step because the HSV model is significantly more robust for color detection under varying lighting conditions compared to the RGB model. Hue represents the color, Saturation represents the color's intensity, and Value represents the brightness. By isolating these components, the algorithm can reliably identify colored objects regardless of shadows or bright spots.

II. Environmental Perception and Feature Extraction:

With the image properly formatted, the algorithm proceeds to analyze its content to understand the robot's surroundings. This is where the two challenges begin to show notable differences.

Core Feature Extraction (Common to Both Challenges)

Both algorithms are designed to detect three primary environmental features:

34

- Wall/Boundary Detection: The darkest areas of the image are classified as walls or boundaries. This is achieved by thresholding the Value (V) component of each pixel in the HSV image. Any pixel with a Value below a certain threshold (specifically, 70) is considered part of a wall. The algorithm then calculates the proportion of wall pixels on the left half of the screen versus the right half, creating left_wall and right_wall metrics. These values are fundamental for the robot's steering logic, enabling it to stay centered on the track.
- Colored Line Detection: The algorithm is programmed to detect two specific colored lines that serve as quadrant markers:
- Blue Line: Detected by identifying pixels with a Hue between 90 and 135 and specific Saturation and Value ranges.
- Orange Line: Detected by identifying pixels with a Hue between 0 and 30 and specific Saturation and Value ranges.

When the number of detected blue or orange pixels crosses a predefined threshold, the system registers the passage of a line, which is used to increment a quadrant_count. This acts as an odometer, tracking the robot's progress along the course.

Advanced Feature Extraction (Exclusive to obstacle challenge algorithm)

The obstacle challenge algorithm script includes a more complex perception system designed for a more challenging environment that includes traffic lights and a final parking task.

- Traffic Light Detection: This version of the algorithm actively searches for red and green objects, which are presumed to be traffic lights. It does this by creating binary "masks" for each color:
- Red Mask: Isolates pixels with a Hue less than 15 or greater than 175.
- Green Mask: Isolates pixels with a Hue between 45 and 90.

After creating these masks, it uses OpenCV's findContours function to identify distinct shapes. The script then analyzes these shapes (contours) to find the largest

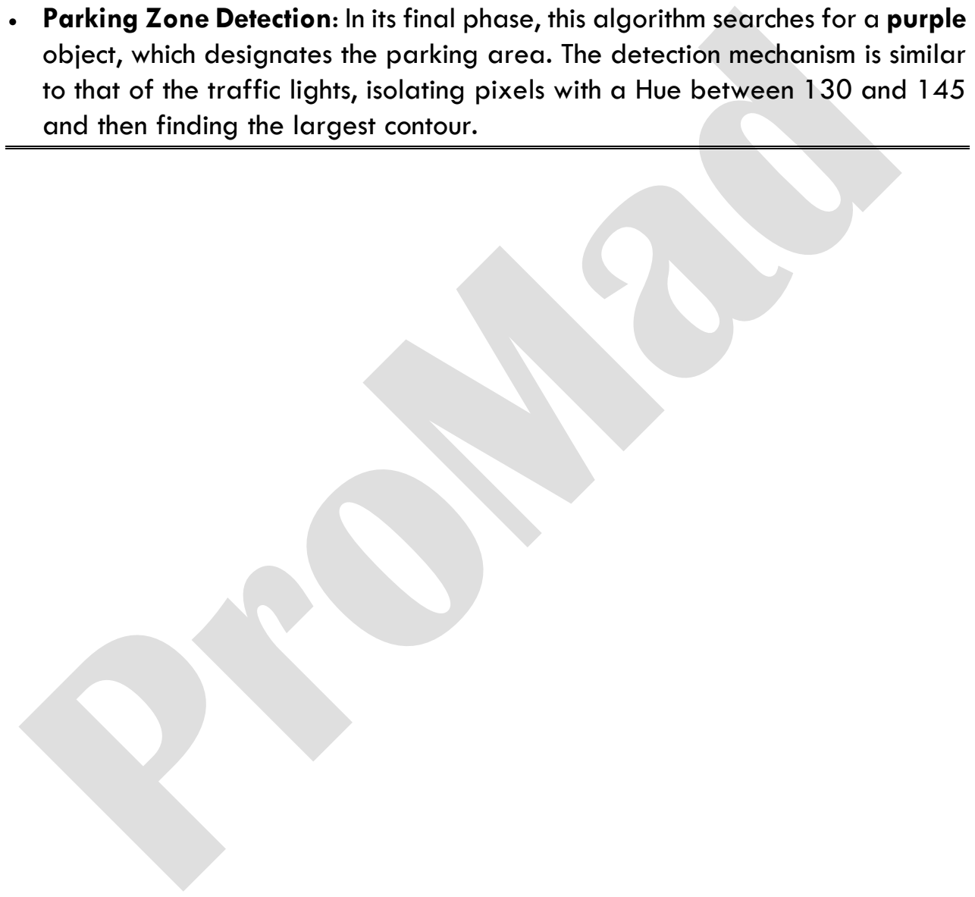
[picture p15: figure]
and then finding the largest contour.

35

valid traffic light, filtering them by area and aspect ratio (vertical rectangles). This allows the robot to identify and react to traffic signals.

- Parking Zone Detection: In its final phase, this algorithm searches for a purple object, which designates the parking area. The detection mechanism is similar to that of the traffic lights, isolating pixels with a Hue between 130 and 145

36

Figure 44: Camera View

### 4.2 Camera Position:

d

CRUCIAL FOR THE ROBOT’S PERFORMANCE!!

To ensure accurate visual input, the camera must be positioned precisely

### 10 centimeters above the ground from the center of the sensor, allowing it to

capture only the designated game field. Any elements outside this boundary— such as clothing items like green shirts—may be mistakenly interpreted by the robot as part of the operational environment. Consequently, the robot may attempt to address non-existent tasks, leading to unnecessary or erroneous actions.

To verify the correct positioning, the camera must be placed exactly 10 centimeters from the ground, ensuring that no part of the pillar is visible above its top edge. The captured view must precisely match the reference shown in Figure 44, confirming that the camera is aligned solely with the intended game field.

Figure 45: Camera Position

37

In the following, we aim to clarify as much as possible the importance of the camera position through some examples:

Figure 46: The camera is positioned too low, causing it to capture areas beyond the walls and outside the game field. This misalignment may result in unintended visual input.

Figure 47: The camera is positioned too high, and when it encounters the walls, it is forced to capture external elements beyond the game field, potentially leading to false interpretations.

Figure 48: The camera is correctly positioned, ensuring that only the game field is visible. With this alignment, the mission will proceed successfully and without interference.

Figure 46: Camera Lower | Figure 47: Camera Higher | Figure 48: Correct Position

38

### 5. The Evolution of The Robot:

### 5.1 Past:

In this section, we explore the earlier stages of our robot’s development, including its initial design, and the key changes we made along the way.

### Initial Designs:

Our primary goal was to create a robot that was both simple and user-friendly— an accessible tool for learning, yet robust enough to tackle complex challenges effectively. With that in mind, we opted for a LEGO-based structure, which successfully completed the assigned tasks. However, despite its functionality, the design presented several limitations that became apparent during testing. These shortcomings prompted us to reconsider and refine our approach, leading to significant improvements over time.

Figure 49: The LEGO Design

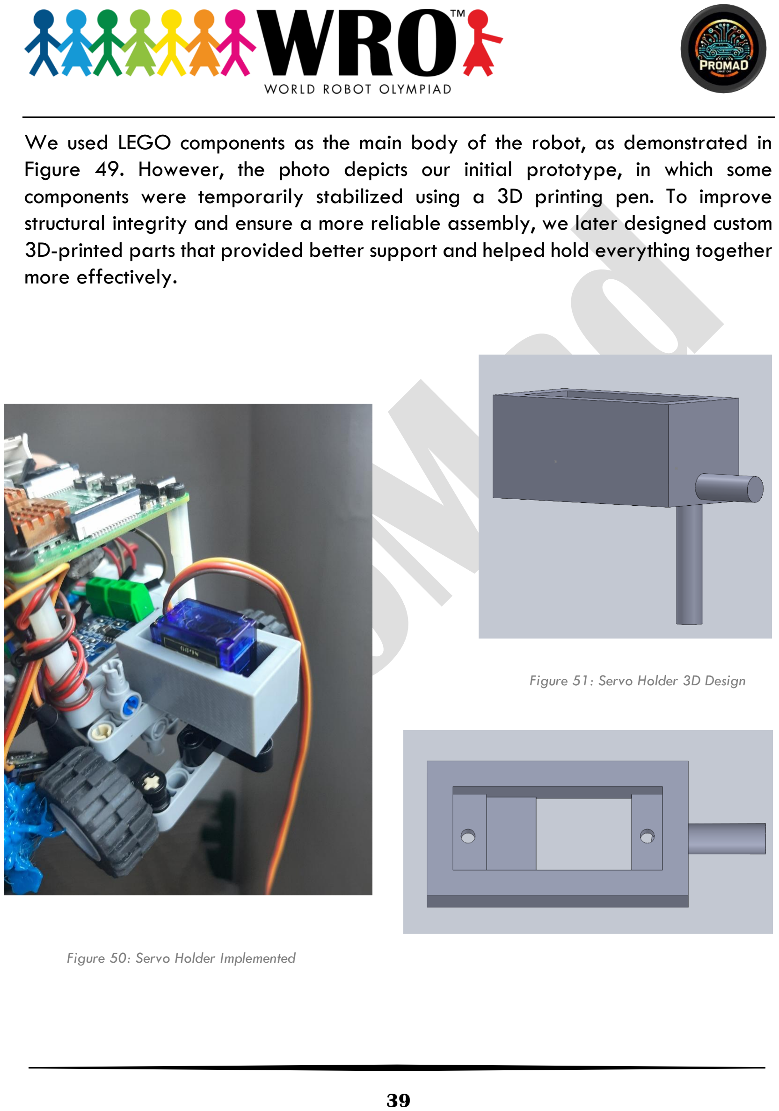
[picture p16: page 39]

39

We used LEGO components as the main body of the robot, as demonstrated in Figure 49. However, the photo depicts our initial prototype, in which some components were temporarily stabilized using a 3D printing pen. To improve structural integrity and ensure a more reliable assembly, we later designed custom 3D-printed parts that provided better support and helped hold everything together more effectively.

Figure 51: Servo Holder 3D Design

Figure 50: Servo Holder Implemented

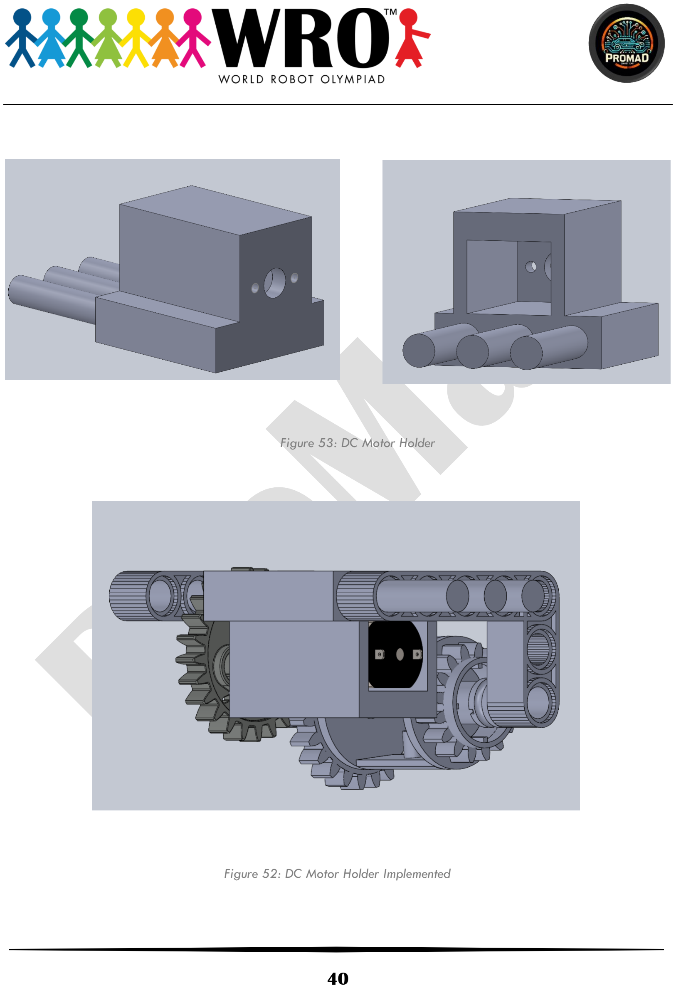
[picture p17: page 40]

40

Figure 53: DC Motor Holder

Figure 52: DC Motor Holder Implemented

41

Challenges with the Initial Design

Our early prototype faced several structural limitations that hindered its overall stability and functionality:

- Many components were held together using temporary fixtures, without a reliable long-term solution.
- The available LEGO parts were slightly flexible, which conflicted with the rigidity required by our core design.
- The layout did not allow for a secure placement of the battery, making power management difficult.

In response to these issues, we explored more durable alternatives. This led to the development of our current design, which incorporates custom 3D-printed components to enhance stability and ensure a more cohesive build.

Power Supply Limitations

Moreover, at the time this design was implemented, our custom power supply circuit had not yet been developed. As a result, the structure was not equipped to accommodate or support the electrical components effectively. This limitation further highlighted the need for a more integrated and adaptable design approach.

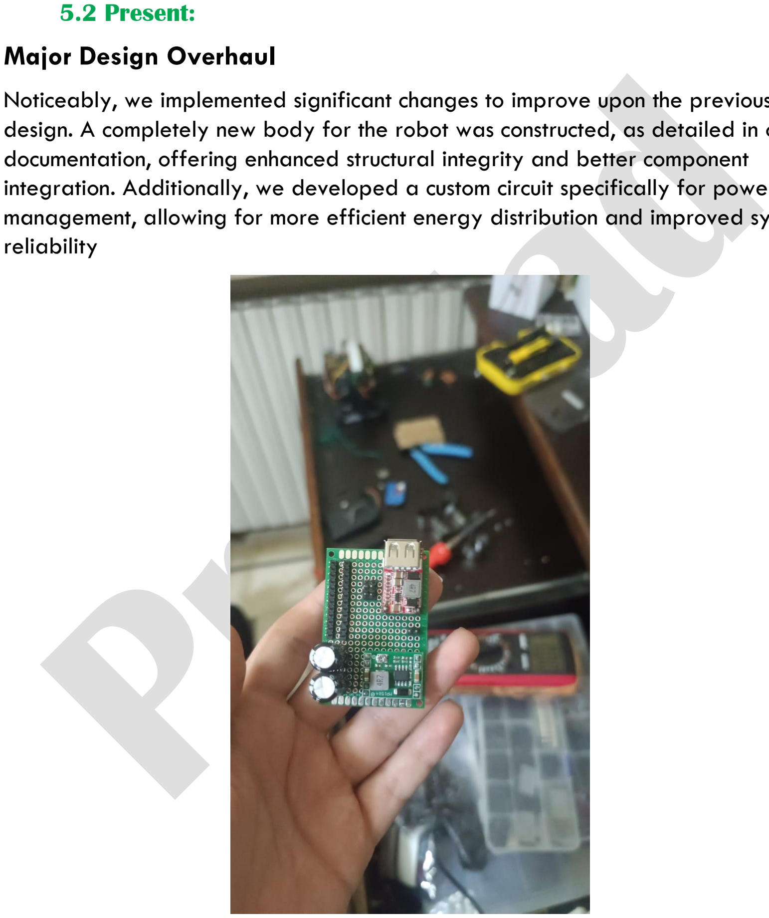
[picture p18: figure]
5.2 Present:; Major Design Overhaul; reliability

42

Noticeably, we implemented significant changes to improve upon the previous design. A completely new body for the robot was constructed, as detailed in our documentation, offering enhanced structural integrity and better component integration. Additionally, we developed a custom circuit specifically for power management, allowing for more efficient energy distribution and improved system

Figure 54: Our Custom Power Circuit

43

### 5.3 Future:

Future Possible Developments

We have extensively considered the future development of this design from multiple perspectives—including the body structure, the underlying algorithm, and other critical components—which will be thoroughly presented in the following section.

The Robot’s Design:

We plan to modify several components of the robot in order to reduce its overall size. These adjustments include:

- The Batteries: One potential solution to reduce the robot’s overall size is to use micro batteries, which offer compact energy storage without significantly compromising performance. If micro batteries are not feasible due to power requirements or availability, we propose repositioning the existing battery setup. Specifically, placing the batteries in a vertical orientation could help minimize the robot’s width, thereby contributing to a more streamlined design.
- The Motor Driver: To further reduce the robot’s size, we considered using more compact motor drivers. The DRV888 motor driver was a promising candidate due to its small footprint and performance capabilities. However, excessive heat generation during operation made it unsuitable for our current design. If thermal management issues can be resolved—either through improved heat dissipation techniques or alternative cooling solutions—we strongly recommend adopting the DRV888, as it would significantly contribute to downsizing the robot.

Figure 56: DRV888 Motor Driver Figure 55: Micro Batteries

44

- Replacing the Raspberry Pi 4 Model B: To achieve a more compact design, we consider replacing the Raspberry Pi 4 Model B with either the Raspberry Pi Pico 2W or the Raspberry Pi Zero 2W. Among these options, the Raspberry Pi Zero 2W is particularly recommended due to its relatively fast processing capabilities and user-friendly architecture. This substitution would significantly contribute to downsizing the robot while maintaining sufficient computational performance for most tasks.
- The Custom Perfboard: The custom perfboard will remain an integral part of the robot’s design, as it plays a crucial role in simplifying power distribution across components. However, to optimize spatial efficiency, we propose repositioning the perfboard vertically. This adjustment would help reduce the overall width of the robot without compromising functionality or accessibility.

Figure 58: Rpi Zero 2w

Figure 57: Rpi Pico 2W

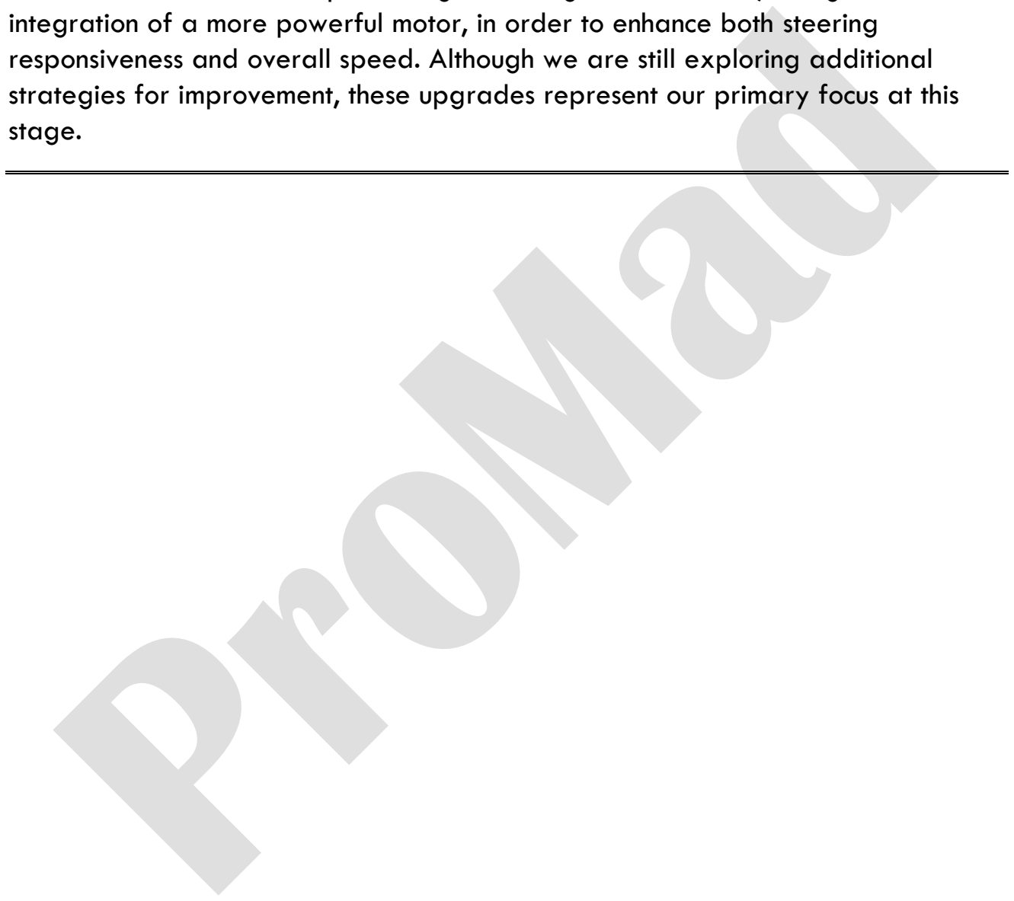
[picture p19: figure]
stage.

45

The Algorithm:

We aim to achieve faster processing and a higher frame rate, alongside the integration of a more powerful motor, in order to enhance both steering responsiveness and overall speed. Although we are still exploring additional strategies for improvement, these upgrades represent our primary focus at this

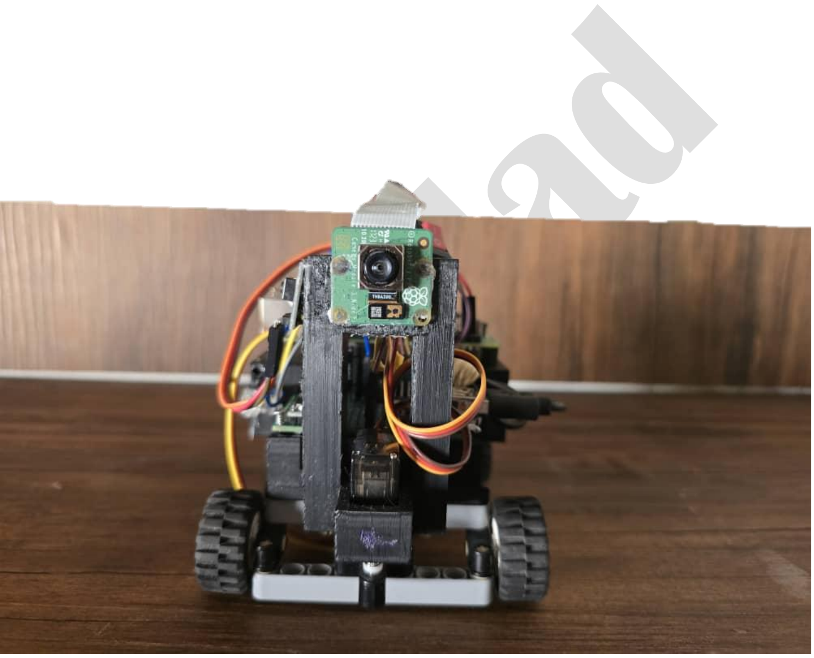
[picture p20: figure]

46

### 6. The Vehicle’s Photos:

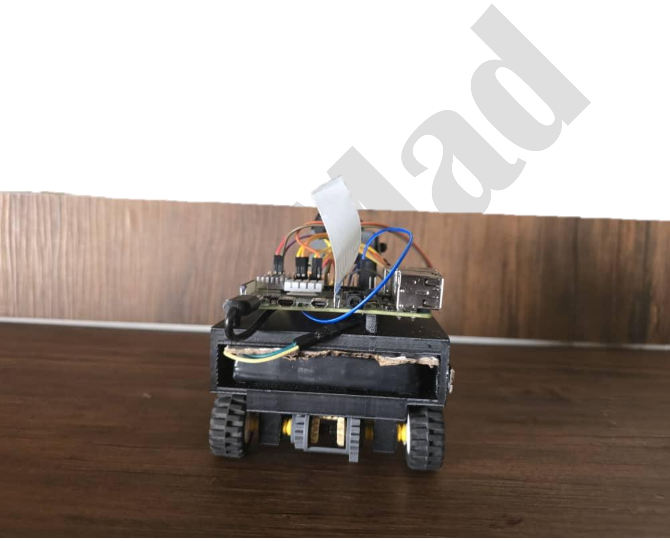
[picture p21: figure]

47

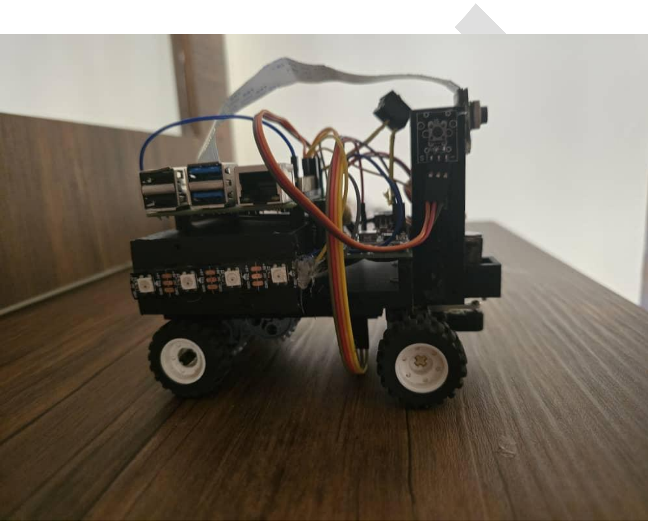
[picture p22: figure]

48

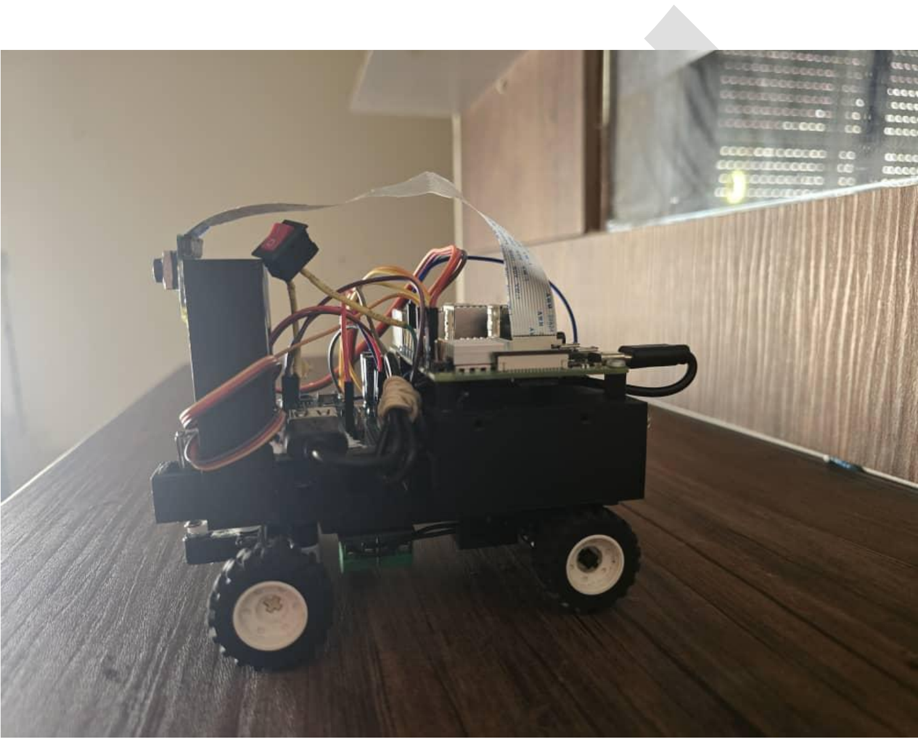
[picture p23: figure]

49

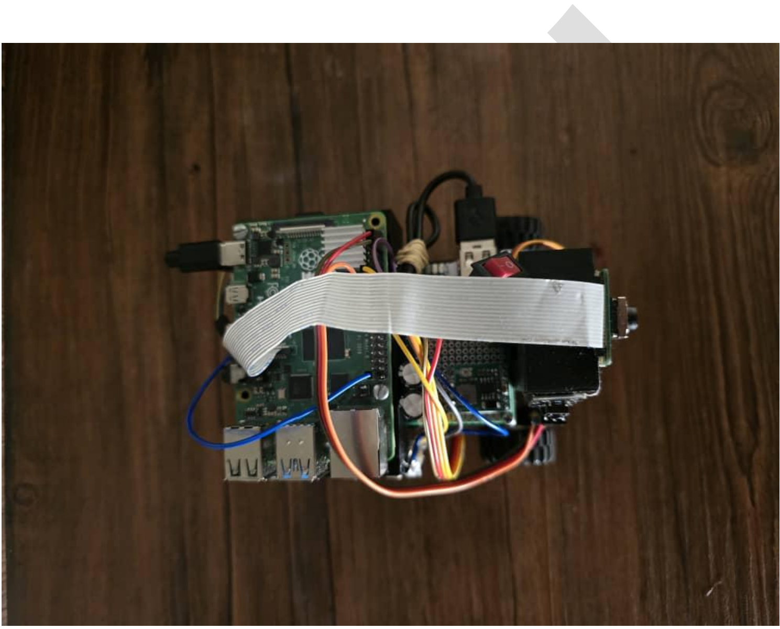
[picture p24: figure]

50

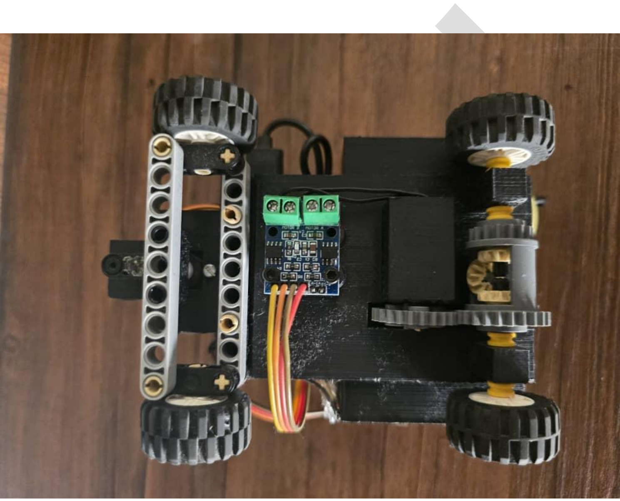
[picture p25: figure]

51

52

### 7. Links and Credits:

Component Links:

Raspberry Pi 4 Model B: | Amazon Link (https://www.amazon.nl/RPI4-MODBP-4GB-Raspberry-Pi-Model-4GB/dp/B09TTNF8BT)
Raspberry Pi Camera v3 Wide: | Amazon Link (https://www.amazon.nl/-/en/Raspberry-Pi-Camera-Module-Wide/dp/B0BRY757NX)
MG90s Mini Servo Motor: | Amazon Link (https://www.amazon.nl/-/en/AZDelivery-Servo-compatible-Arduino-Including/dp/B086V8RKZR)
GA12-N20 Geared Mini DC Motor 150Rpm / 12V | Amazon Link (https://www.amazon.nl/-/en/Stepper-GA12-N20-Sprocket-100RPM-1000RPM/dp/B0DK8DVYJH)
L9110 Motor Driver: | Amazon Link (https://www.amazon.nl/-/en/L9110S-H-Bridge-Stepper-Driver-Controller/dp/B07KFLZKP1)
LiPo Batteries: | Amazon Link (https://www.amazon.nl/-/en/Lithium-505573-2500mAh-wireless-charging-lightbox/dp/B08748XRY4?xpid=RZmlEG9Emw43-)
20A BMS: | Amazon Link (https://www.amazon.nl/-/en/sspa/click?sp_cr=DUB)
Mini 360 DC-DC Buck Converter: | Amazon Link (https://www.amazon.nl/-/en/Regulator-Step-Down-Converter-4-75-23V-Adjustable/dp/B0CW9MGLZ2)
DC-DC Buck Converter Module with USB Type-A Output: | Amazon Link (https://www.amazon.nl/-/en/2pcs-6-24V-Module-DC-DC-Converter/dp/B07JLTTZXL)
Perfboard: | Amazon Link (https://www.amazon.nl/-/en/Breadboard-4cm%C3%976cm-Circuit-Soldering-Electronic/dp/B07R1W6169)
470uf / 25V Capacitor: | Amazon Link (https://www.amazon.nl/-/en/Electrolytic-Capacitors-electrolytic-capacitors-applications/dp/B0F9K62QPW)
LEGO Kits | Amazon Link (https://www.amazon.nl/-/en/Technic-Replacement-Building-Normal-mechanical/dp/B0BN28363D)
STL Files; | Link (https://github.com/ProMad24/WRO-Future-Engineers-2025/tree/main/3d%20Models)

Main Links:

GitHub Link QR + Link (https://github.com/ProMad24/WRO-Future-Engineers-2025/tree/main) / Open Challenge (https://youtu.be/HfWMtbpaqr4) | / | Obstacle Challenge (https://youtu.be/K1ZzTWNqTTs)

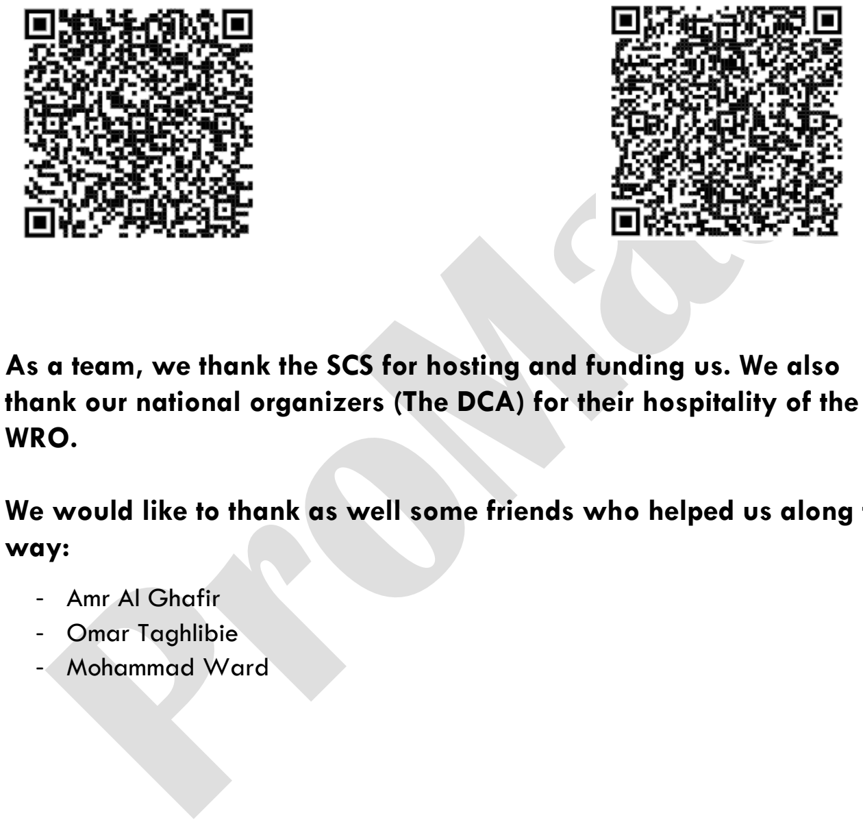
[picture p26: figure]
WRO.; way:; - Amr Al Ghafir - Omar Taghlibie - Mohammad Ward

53

Open Challenge Code | Obstacle Challenge Code (https://github.com/ProMad24/WRO-Future-Engineers-2025/blob/main/Source%20Codes/ObstacleChallenge.py)

As a team, we thank the SCS for hosting and funding us. We also thank our national organizers (The DCA) for their hospitality of the

We would like to thank as well some friends who helped us along the

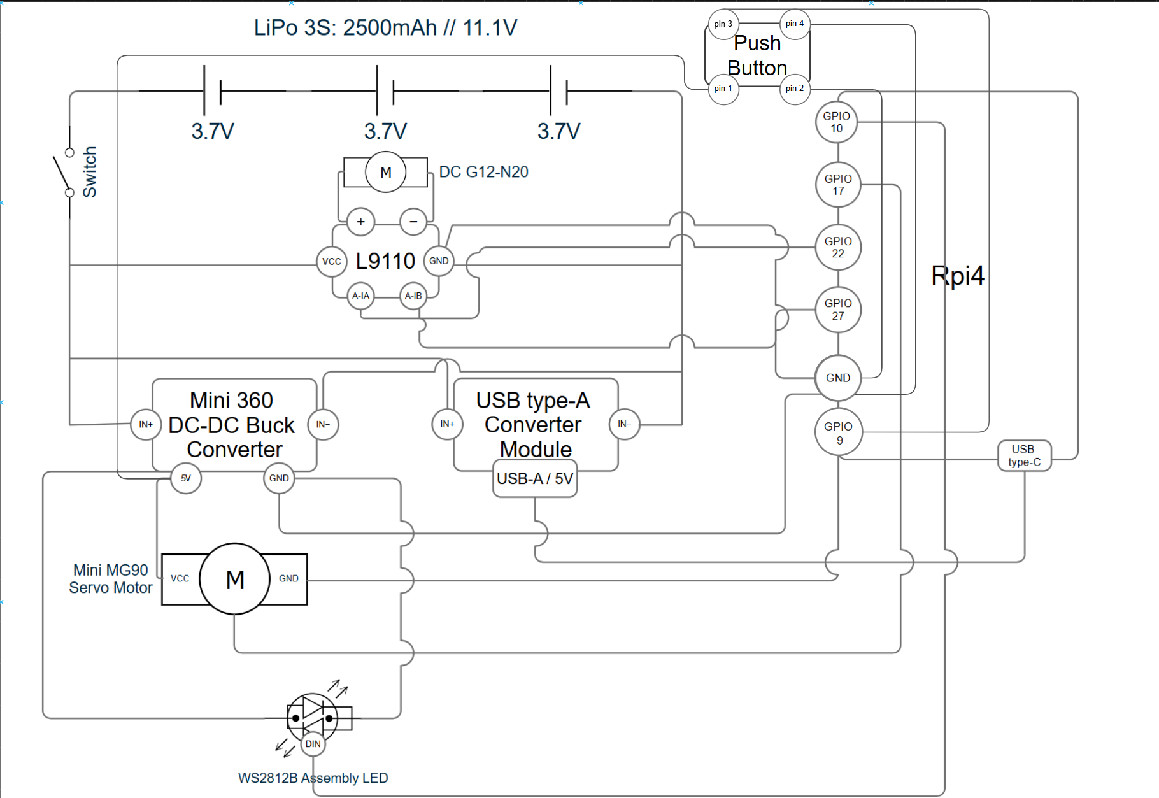
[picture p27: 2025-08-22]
Schemes and Electromechanical Components/Schematics.png

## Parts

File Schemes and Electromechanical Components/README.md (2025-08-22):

# Schemes and Electromechanical Components

Here we present the wiring diagrams, schemes, and photos of the electromechanical components

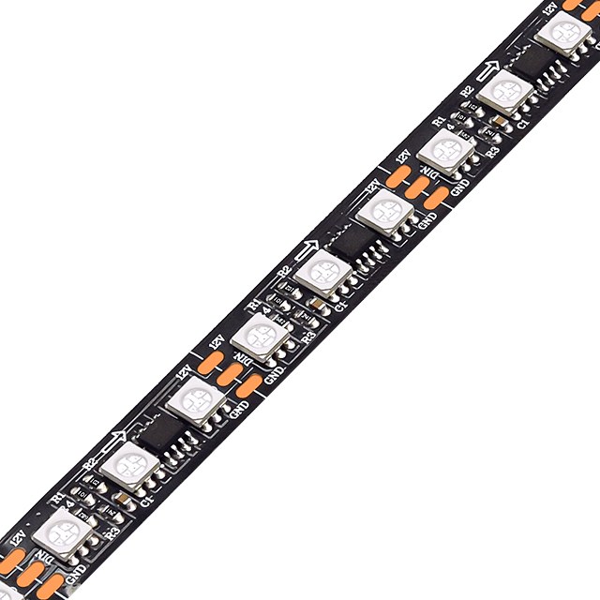
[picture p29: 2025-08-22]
Schemes and Electromechanical Components/WS2812B.jpg

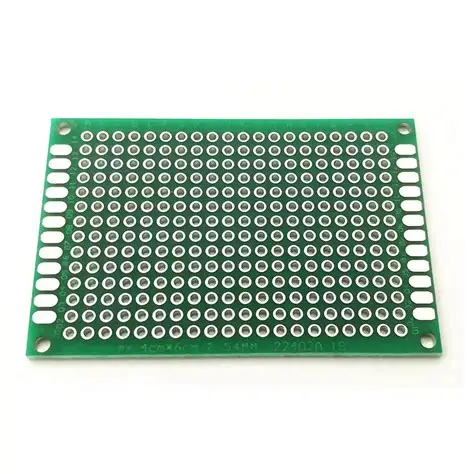
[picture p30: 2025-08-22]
Schemes and Electromechanical Components/Perfboard.webp

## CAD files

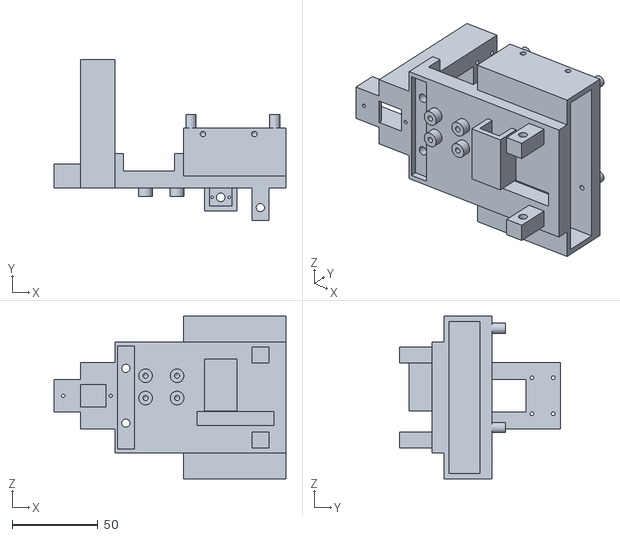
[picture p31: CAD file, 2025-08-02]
3d Models/Base.STL
135.5 x 94.0 x 95.0

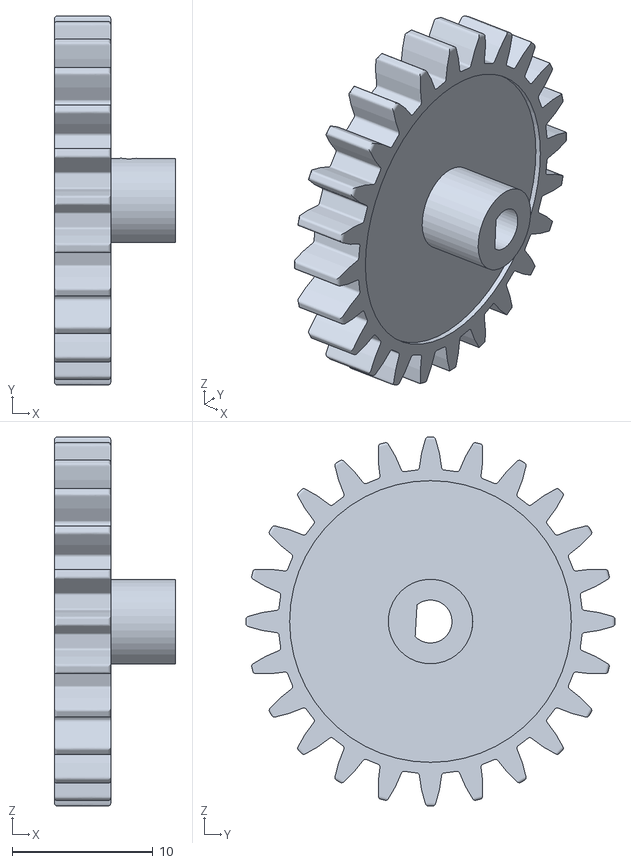
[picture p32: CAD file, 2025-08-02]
3d Models/DC Gear.STL
8.60 x 26.2 x 26.2

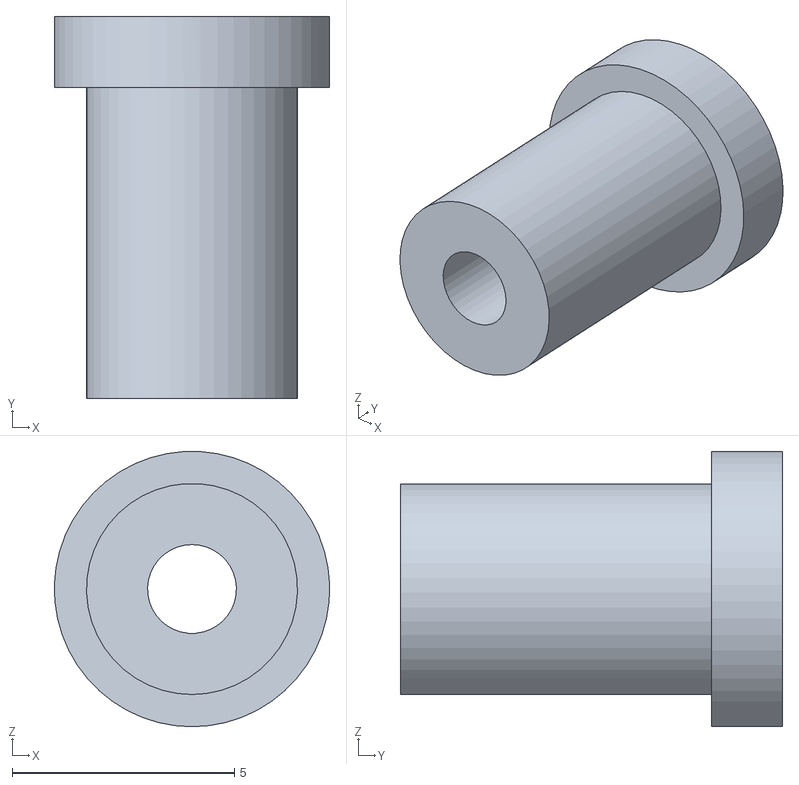
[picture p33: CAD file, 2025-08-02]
3d Models/ServoScrewHolder.STL
6.20 x 8.60 x 6.20

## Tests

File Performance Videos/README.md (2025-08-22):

# Performance Videos:

Here we present to you vidoes of the robot solving its tasks.

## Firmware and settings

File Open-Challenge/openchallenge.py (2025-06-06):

#!/usr/bin/env python3

import cv2
import sys
import board
import numpy as np
import time
from picamera2 import Picamera2, Preview
import RPi.GPIO as GPIO
import neopixel  # Import the neopixel library 
# Define constants
SERVO_PIN = 17
MOTOR_IN1 = 27
MOTOR_IN2 = 22

OUTPUT = GPIO.OUT
INPUT = GPIO.IN
# --------------------------------------------------

STOP = False
mission_end_cycle = int(1e9)
mission_end_not_activated = True

cycle_count = 0
direction = 0
quadrant_count = 0

hue = 0

# --------------------------------------------------
# Image variables

raw_frame = np.empty((480, 640, 3), dtype=np.uint8)
frame = np.empty((120, 320, 3), dtype=np.uint8)
hsv = np.empty((120, 320, 3), dtype=np.uint8)

# --------------------------------------------------
# Wall variables

left_wall = 0.0
right_wall = 0.0

# --------------------------------------------------
# Map lines variables

line_cycle_delay = 10

blue_line_threshould = 1500
orange_line_threshould = 1500

blue_line_pixel_count = 0
blue_line_next_allowed_cycle = 0

orange_line_pixel_count = 0
orange_line_next_allowed_cycle = 0

blue_line_detected = False
orange_line_detected = False

blue_line_state = 0
orange_line_state = 0

# --------------------------------------------------
# P controller variables

kp = 0.25
Err = 0

dir = 0.0

# --------------------------------------------------

def LED_color(r, g, b):
    for i in range(4):
        pixels[i] = (r, g, b)
    pixels.show()
def LED_hsv(hue_val, sat, val):
    #
    # Convert an HSV color to RGB and set the LED accordingly
    r = g = b = 0
    # Normalize hue to the range [0, 360] for full color spectrum
    h = hue_val * 2.0  # Multiply by 2 to scale to [0, 360]
    s = sat / 255.0  # Saturation (1.0 for full saturation)
    v = val / 255.0  # Value (1.0 for full brightness)

    i = int(h / 60.0) % 6  # Find which sector of the color wheel we're in
    f = h / 60.0 - i  # Calculate the fractional part of hue

    p_val = v * (1.0 - s)
    q_val = v * (1.0 - f * s)
    t_val = v * (1.0 - (1.0 - f) * s)

    if i == 0:
        r = v * 255
        g = t_val * 255
        b = p_val * 255
    elif i == 1:
        r = q_val * 255
        g = v * 255
        b = p_val * 255
    elif i == 2:
        r = p_val * 255
        g = v * 255
        b = t_val * 255
    elif i == 3:
        r = p_val * 255
        g = q_val * 255
        b = v * 255
    elif i == 4:
        r = t_val * 255
        g = p_val * 255
        b = v * 255
    elif i == 5:
        r = v * 255
        g = p_val * 255
        b = q_val * 255

    LED_color(int(r), int(g), int(b))
def servo(angle):
    """Adjust and set the servo angle using RPi.GPIO."""

    global SERVO_PIN

    angle += 60
    deviation = 55
    if angle < 60 - deviation:
        angle = 60 - deviation
    if angle > 60 + deviation:
        angle = 60 + deviation
    angle += 0

    min_duty = 2.5  # Duty cycle for 0 degrees
    max_duty = 12.5 # Duty cycle for 180 degrees

    duty_range = max_duty - min_duty
    duty = min_duty + (angle / 180.0) * duty_range

    servo_pwm.ChangeDutyCycle(duty)
    time.sleep(0.1)
    servo_pwm.ChangeDutyCycle(0)
def motor(speed):  # Speed is -1 to 1
    global MOTOR_IN1, MOTOR_IN2

    speed = max(-100, min(100, speed))
    speed_pwm = abs(speed)  # Calculate absolute speed for PWM

    if speed > 0:  # Forward

        motor1_pwm.ChangeDutyCycle(speed_pwm)
        motor2_pwm.ChangeDutyCycle(0)
    elif speed < 0:  # Reverse
        motor1_pwm.ChangeDutyCycle(0)
        motor2_pwm.ChangeDutyCycle(speed_pwm)
    else:  # Stop
        motor1_pwm.ChangeDutyCycle(0)
        motor2_pwm.ChangeDutyCycle(0)


def Setup_GPIO():
    GPIO.setmode(GPIO.BCM)

    GPIO.setup(SERVO_PIN, OUTPUT)
    GPIO.setup(MOTOR_IN1, OUTPUT)
    GPIO.setup(MOTOR_IN2, OUTPUT)
    GPIO.setup(10, OUTPUT)
    global servo_pwm, motor1_pwm, motor2_pwm,pixels
    servo_pwm = GPIO.PWM(SERVO_PIN, 50)
    servo_pwm.start(0)

    motor1_pwm = GPIO.PWM(MOTOR_IN1, 1000)
    motor2_pwm = GPIO.PWM(MOTOR_IN2, 1000)
    motor1_pwm.start(0)
    motor2_pwm.start(0)

    # Initialize NeoPixels
    pixels = neopixel.NeoPixel(board.D10, 4, brightness=0.2, auto_write=False, pixel_order=neopixel.GRB)

def Setup_Camera():
    global picam2
    picam2 = Picamera2()
    config = picam2.create_preview_configuration(
        main={"format": 'RGB888', "size": (640, 480)})
    picam2.configure(config)
    picam2.start()
    time.sleep(1)
    return picam2


def capture_array(picam2):
    raw_frame_arr = picam2.capture_array()
    return raw_frame_arr


def process_frame(raw_frame_arr, frame_arr):
    i = 0
    f = 120 * 320 * 3 - 3

    raw_flat = raw_frame_arr.reshape(-1)
    frame_flat = frame_arr.reshape(-1)

    for y in range(240, 480, 2):
        for x in range(0, 640, 2):
            frame_flat[f] = raw_flat[i]
            frame_flat[f + 1] = raw_flat[i + 1]
            frame_flat[f + 2] = raw_flat[i + 2]
            i += 6
            f -= 3
        i += 640 * 3


def process_hsv(hsv_arr):
    global blue_line_pixel_count, orange_line_pixel_count, left_wall, right_wall
    blue_line_pixel_count = 0
    orange_line_pixel_count = 0

    left_wall = 0.0
    right_wall = 0.0

    i = 0
    j = 0
    total_pixels = 120 * 320
    hsv_flat = hsv_arr.reshape(-1)
    for p in range(total_pixels):
        hue_val = int(hsv_flat[i])
        sat = int(hsv_flat[i + 1])
        val = int(hsv_flat[i + 2])
        if sat > 60 and val > 90 and val < 240:
            if 90 < hue_val < 135:
                blue_line_pixel_count += 1

        if sat > 30 and val > 60 and val < 240:
            if 15 <= hue_val <= 45:
                orange_line_pixel_count += 1

        if val < 70:
            if j < 160:
                left_wall += 1
            else:
                right_wall += 1

        i += 3
        j = (j + 1) % 320

    left_wall /= (160 * 80)
    right_wall /= (160 * 80)
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

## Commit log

2025-06-06 Create Raspberry Pi 4 Model B.md
2025-06-06 Create Raspberry Pi Camera Module 3.md
2025-06-06 Create Geared Mini DC Motor.md
2025-06-06 Create L9110 Motor Driver.md
2025-06-06 Create SG90 Servo Motor.md
2025-06-06 Create 3S Li-ion Battery Pack with 20A Protection Circuit.md
2025-06-22 Rename 3S Li-ion Battery Pack .png to 3S LiPo Battery Pack .png
2025-06-22 Verifying information about the 3S LiPo Battery Pack with 20A Protection Circuit.md
2025-08-22 Update and rename Others/Electromechanical Components/SG90 Servo Motor.md to Schemes and Electromechanical Components/MG90 Servo Motor.md
2025-08-22 Update and rename MG90 Servo Motor.md to README.md
